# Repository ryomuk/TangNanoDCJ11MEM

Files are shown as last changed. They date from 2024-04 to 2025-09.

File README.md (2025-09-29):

# TangNanoDCJ11MEM
Memory system and UART implemented on Tang Nano 20K for DEC DCJ11 PDP-11 Processor

This document is written mostly in Japanese. If necessary, please use a translation service such as DeepL (I recommend this) or Google.

- 本プロジェクトはTang Console 138Kを用いた続編[TangConsoleDCJ11MEM](https://github.com/ryomuk/TangConsoleDCJ11MEM)があります．
- このREADMEおよび[hdl.old](./hdl.old)フォルダ配下のREADMEに書かれている不安定である旨の記述は2024年に作成したrev1.1基板のものです．rev.2.2になってかなり安定しましたが，記録として残しておきます．

# 概要
- PDP-11の命令セットを持つCPU「DEC DCJ11」のメモリシステムとUARTをFPGA(TangNano20K)上に実装する試みです．信号のインターフェース部分に[tangNano-5V](https://github.com/ryomuk/tangnano-5V)を使用しています．(rev.3.1基板では不要)
- FPGAに実装するのはメモリやUARTなどの周辺回路部分だけで，CPU自体は本物を使用します．ソフトウェアやFPGAによるシミュレータやエミュレータではなく，本物のCPUを動かします．
- "TangNanoDCJ11"だとTangNano上にDCJ11を実装したみたいな名前になってしまうので，"MEM"を付けて"TangNanoDCJ11MEM"という名前になっています．
- まずベアメタルで動かしたところ安定して動きました．
- 次に，PC-11(Paper-Tape Reader/Punch)エミュレータでPaper-Tape BASICをロードして実行することができました．
- さらに，UNIX first edition (UNIX V1)を動かすために，ディスク(RF11, RK11)や外部演算装置(KE11)のエミュレータを実装したところ，それなりに動くようになりました．

# 最近の話題
- 2025/09/03: 本プロジェクトの続編[TangConsoleDCJ11MEM](https://github.com/ryomuk/TangConsoleDCJ11MEM)を公開
- 2025/09/05: rev2.2基板公開
- 2025/09/22: レベル変換ICを搭載した基板rev3.1を公開
- 2025/09/29: RT-11 v4用のHDLを公開
- 最新版は下記の通り
  - レベル変換外付け版([rev2.2](pcb/rev2.2))．(別途[TangNano5V](https://github.com/ryomuk/tangnano-5V)が必要です．)
  - レベル変換搭載版([rev3.1](pcb/rev3.1))
  - 上記のどちらもHDLコードは共通です．
    - [UNIX用のHDLコード](./hdl/unix)(unix-v1, unix-v6 共通)
    - [tapebasic用のHDLコード](./hdl/tapebasic)
    - [RT11v4用のHDLコード](./hdl/rt11v4)

# 主なファイル一覧
```
.
├── diskimage : SDメモリ用データ
│   ├── Caldera-license.pdf : UNIXのライセンス条項
│   ├── sd-unix-v1.dsk      : unix v1用disk image
│   └── sd-unix-v6.dsk      : unix v6用disk image
├── hdl              : rev2.2, rev3.1基板用HDLコード
│   ├── rt11v4
│   ├── tapebasic
│   └── unix
├── hdl.old          : rev1.1基板用HDLコード
│   ├── baremetal
│   ├── tapebasic
│   ├── unix-v1
│   └── unix-v6
├── pcb
│   ├── rev1.1      : rev1.1基板
│   ├── rev2.2      : rev2.2基板
│   └── rev3.1      : rev3.1基板
└── README.md        : このファイル
```
- diskimageフォルダ内にあるSDメモリ用のイメージファイルはUNIXのオリジナルソースからの派生物なので，ライセンス条件は Caldera-license.pdf (昔のBSD?)に従います．
- その他の部分についてはMITライセンスです．

## Gowin FPGA Designerの設定について
- implフォルダをgitから除外したら設定ファイルも除外されてしまったのでコンパイル時にエラーが出るかもしれません．Configuration->Dual-Purpose Pin で"Use SSPI as regular IO"をチェックし下さい．
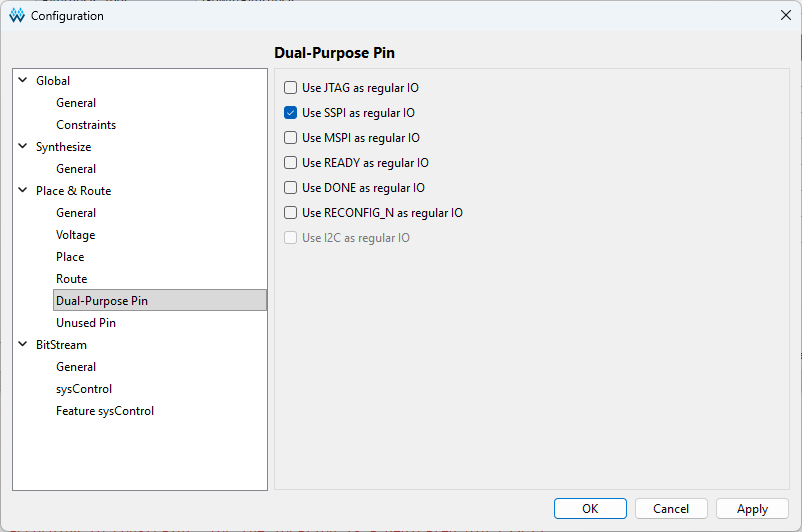
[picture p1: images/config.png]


# 基板のバージョンについて
- [TangConsole138Kを用いたプロジェクト](https://github.com/ryomuk/TangConsoleDCJ11MEM)を開始した際に，CLK2に同期させるとかなり安定するという知見が得られたので，アップデートするついでに各種パッチを反映させた基板(rev2.2)を作成しました．
- ついでに，レベル変換を搭載した基板(rev3.1)も作成しました．
- それぞれの基板は下記のような関係にあります．
```
rev1.1
↓ unix v1, v6用パターンカット，ジャンパ, HALTのダイオード追加, CLK2同期化
rev2.2
↓ レベル変換(TangNano5V相当)を基板上に搭載(CPUの入力信号(FPGA→CPU)については省略)
rev3.1
```
- rev1.1基板に「unix-v1, v6用のパターンカット，ジャンパ線」，「CLK2とGPIO_RXを33Ωで接続」，「HALTのダイオード」を追加することでrev2.2基板と同じ回路になり，rev2.2基板用のHDLコードで動作します．
- rev3.1基板はrev2.2基板にレベル変換を搭載しただけなので同じHDLコードが動きます．
- rev1.1基板用のHDLコードはrev2.2, rev3.1基板では動きません．

# ハードウェア
## FPGAに実装した機能
- Initialization Sequence時のPower-Up Configuration Register設定
- メモリ 32K×16bit
- UART．TangNanoのUSB経由およびGPIO経由の2系統．シリアルの設定は基本的には115200bps,8N1Nにしています．(UNIX V6だと7N1Nにしないと文字化けする現象あり．)
- BS0, BS1は見ていません．TangNano20Kではピンが足りなかったのと，DAL[15:0]とAIO[3:0]を見ればとりあえず十分だったので．
- DAL[21:16]も見ていません．
- PC-11(Paper-Tape Reader/Punch)エミュレータを実装しました．(Paper tape BASICを実行する用で，UNIXでは動きません．)
- ディスクドライブ(RF11, RK11)，外部演算装置(KE11-A)，クロック(KW11-L)等，UNIX V1の動作に必要な装置のエミュレータを実装しました．

## rev3.1基板 (PCB rev3.1)
- レベル変換ICを基板上に実装しました．これによりTang Nano 20KをTangNano5Vを使わずに直接搭載できます．
- ピンアサインはrev2.2基板と同じなので，FPGA用のコードはrev2.2用のものを使用します．
- WS2812のアレイを接続するための端子を用意しました．
- レベル変換ICのOE_nをdisableにしてCPUとTangNanoを切り離すためのジャンパ端子を用意しました．(初めて搭載するときなど，FPGAに別の回路が書かれているようなとき用．)
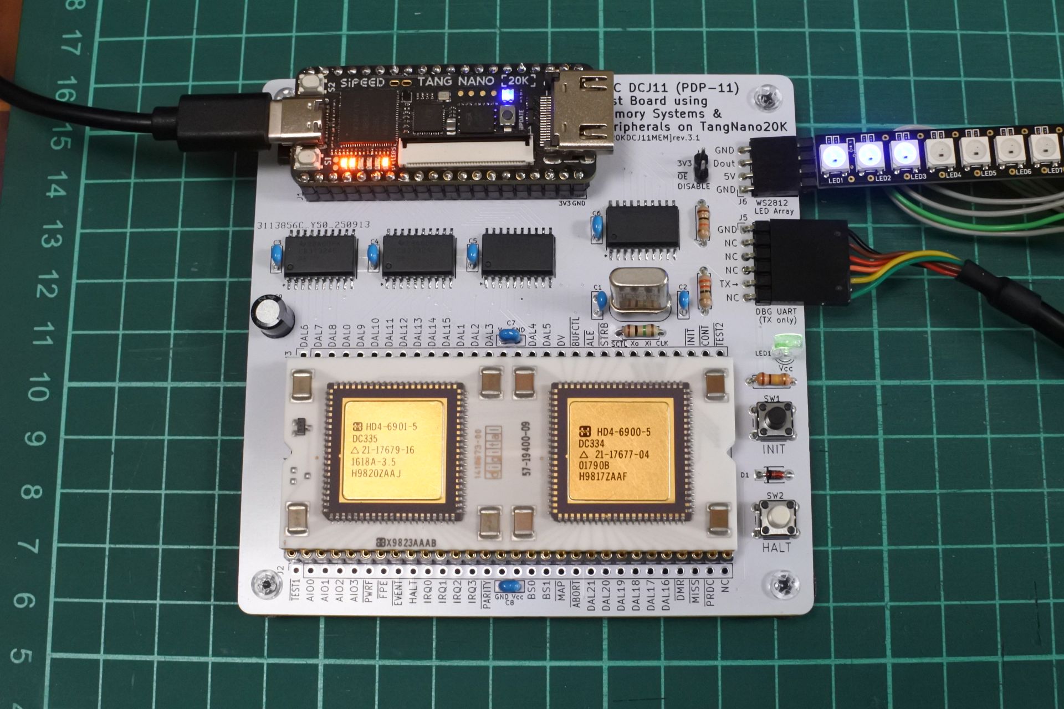
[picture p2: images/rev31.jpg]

#### BOM (PCB rev3.1)
|Reference |Qty| Value |Size |Memo |
|---|---|---|-----|-----|
|C1,C2|2|68pF|||
|C3,C4, C5, C6|4|0.1uF|||
|C7,C8|2|0.33uF|||
|C9 |1|47uF|||
|D1 |1|1N4148|||
|J1 |1|IC socket |40pin DIP 800mil|TangNano20K用．幅800milなので1x20のpin socketを2列実装．|
|J2,J3|2  |pin header or socket|1x30|任意．テストや観測，実験用．|
|J4 |1  |pin header |1x02|任意．OE_nをdisableにする用|
|J5 |1  |pin socket |1x04 L字|WS2812アレイ用|
|J6 |1  |pin header |1x06 L字|UART用|
|LED1 |1||||
|R1 |1|1M|||
|R2 |1|33|||
|R3,R4,R5,R6,R7,R8,R9,R10,R11,R12,R13,R14,R15|13|10k|
|R16|1|100k  || 値はLEDに合わせて任意．|
|SW1,SW2  |2  |tactile SW |6mmxH4.3mm|例: https://akizukidenshi.com/catalog/g/g103647/ |
|U1 |1  |DCJ11 |60pin DIP 1300mil| 1x30 の丸ピンソケット2列|
|U2,U3,U4,U5  |4  |SN74CB3T3245DWR(又は DW) | SOIC-20| パッケージサイズに注意|

|Y1                 |1  |18MHz           |HC49|例: https://mou.sr/3WcWExh , 周波数を変えられるようにソケットの使用をお勧めします．|

- SN74CB3T3245はパッケージサイズに注意．SOIC-20はDWかDWRです．PWやPWRではありません．
- R2は"33k"ではなく"33"です．ダンピング抵抗なので．
- R12，最近のLEDは明るいので100kぐらいでちょうど良かったりします．使うLEDに応じて適切な値を選んで下さい．

## rev2.2基板 (PCB rev2.2)
- rev1.1基板でunixを動かすために必要だったパターンカットとジャンパ配線を反映させました．
- CLK2をGPIO_RXだったピンに入力して，回路をCPUのクロックと同期させました．
- 上記に伴い，基板のUART端子はデバッグログ用のTXだけになりました．
- 電源供給をTangNanoからだけにしてDCジャックを廃止しました．
- HALTスイッチのところの抵抗をダイオードに変更しました．
- unix(v1, v6)を動作させるためのプロジェクトは[hdl/unix](hdl/unix/)を使用して下さい．
- SDメモリ用のイメージファイルは[./diskimage](./diskimage)にあるものがそのまま使えます．
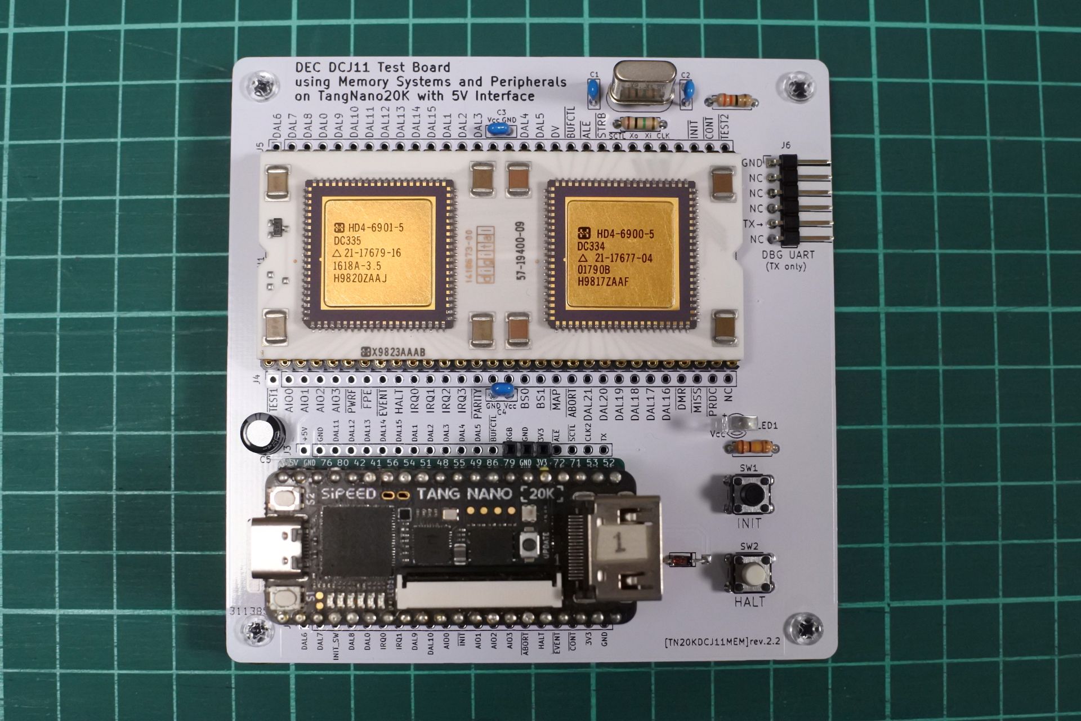
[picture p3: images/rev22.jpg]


#### BOM (PCB rev2.2)
|Reference |Qty| Value |Size |Memo |
|---|---|---|-----|-----|
|C1, C2|2|68pF|||
|C3, C4|2|0.33uF|||
|C5 |1|47uF|||
|D1 |1|1N4148|||
|J1 |1|IC socket |40pin DIP 600mil|TangNano5V用．1x20のpin socket 2列でも可．|
|J2,J3 |2|pin header or socket|1x20|任意．テストや観測，実験用．|
|J4,J5 |2  |pin header or socket|1x30|任意．テストや観測，実験用．|
|J6 |1  |pin header |1x06 L字|UART用|
|LED1 |1||||
|R1 |1|1M|||
|R2 |1|33|||
|R3,R4,R5,R6,R7,R8,R9,R10,R11,R12,R13,R14|12|10k|
|R15|1|100k  || 値はLEDに合わせて任意．|
|SW1,SW2  |2  |tactile SW |6mmxH4.3mm|例: https://akizukidenshi.com/catalog/g/g103647/ |
|U1 |1  |DCJ11 |60pin DIP 1300mil| 1x30 の丸ピンソケット2列|
|Y1 |1  |18MHz |HC49|例: https://mou.sr/3WcWExh , 周波数を変えられるようにソケットの使用をお勧めします．|

## rev1.1基板 (PCB rev1.1)
- rev1.0はいくつか修正箇所があったので修正しました．
- CPUが白いので基板も白くしてみました．
- CPUおよびTangNanoの電源をどこから供給するかを2箇所のジャンパで切り替えられるようにしました．詳細は回路図と基板上のシルクを見て下さい．
- プルダウン抵抗(R2〜R6)を100kから10kに変更しました．(rev1.1a)
- UNIXを動かすにはJP1のパターンのカット，数本のジャンパ配線が必要です．詳細は[UNIX V1](hdl.old/unix-v1/)参照．
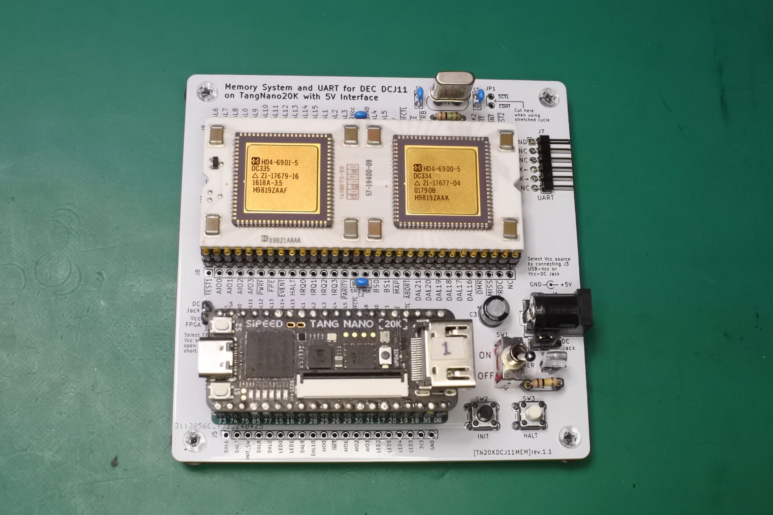
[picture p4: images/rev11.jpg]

#### BOM (PCB rev1.1)
|Reference |Qty| Value |Size |Memo |
|---|---|---|-----|-----|
|C1,C2 |2	|0.33uF	 ||DECのプロセッサボードで0.33uFを使っていたので．0.1uFでもいいかもしれない．|
|C3 |1  |47uF |||
|C4,C5 |2  |68pF |||
|D1 |1  |LED || |
|J1 |1  |DC Jack ||例: https://akizukidenshi.com/catalog/g/g106568/ |
|J2 |1  |pin header |1x02|DC Jackからの5VをTangNanoに供給するとき用．(そのときはTangNanoのUSBは外すこと)．|
|J3 |1  |pin header |1x03|CPUへの5VをDC JackからにするかUSB(TangNano)からにするかの選択用．|
|J4 |1  |IC socket |40pin DIP 600mil|TangNano5V用．1x20のpin socket 2列でも可．|
|J5,J6 |2  |pin header or socket|1x20|任意．テストや観測，実験用．|
|J7 |1  |pin header |1x06 L字|UART用|
|J8,J9 |2  |pin header or socket|1x30|任意．テストや観測，実験用．|
|JP1 | | ||任意．sctl_nとcont_nを切断したときにpin headerを立てる用．実装する場合は先にパターンをカットして下さい．(unix-v1では切断して使います)|
|R1 |1  |100k || 値はLEDに合わせて任意．|
|R2～R6 |5 |10k || プルダウン用．入力電流がmax10μAなので大きめでいいかと思ったら意外にノイズが大きいので100kから10kに変更しました．|
|R7～R16 |10 |100k || プルアップ用．10k〜100kぐらいで任意．|
|R17 |1  |1M |||
|SW1 |1  |toggle SW ||例: https://akizukidenshi.com/catalog/g/g100300/ |
|SW2,SW3 |2  |tactile SW |6mmxH4.3mm|例: https://akizukidenshi.com/catalog/g/g103647/ |
|U1 |1  |DCJ11 |60pin DIP 1300mil| 1x30 の丸ピンソケット2列|
|Y1 |1  |18MHz |HC49|例: https://mou.sr/3WcWExh , 低速(2MHzで確認済み,もっと遅くても動きそう)でも動きます．周波数を変えられるようにソケットの使用をお勧めします．|

# [応用例(hdl.old/)](hdl.old/)
## [ベアメタル(hdl.old/baremetal)](hdl.old/baremetal/)
- クロス環境で作成したプログラムを実行します．
- HDLは小規模なので，いろいろ試すベースラインに最適です．

## [tape basic(hdl.old/tapebasic)](hdl.old/tapebasic/)
- 二次記憶をエミュレートするために手始めに作った習作です．
- PC11(tape reader/pucnch)エミュレータで，tape BASICを読み込んで起動します．
- SDメモリを使う練習用に作ったものなのでとりあえず動きます程度のものです．
- PDP11GUIに，console ODT経由でpaper tape softwareをロードする機能があるようなので，いろいろなpaper tape softwareを試すという目的であればベアメタルでPDP11GUIを使うことをお勧めします．

## [UNIX V1(hdl.old/unix-v1)](hdl.old/unix-v1/)
- SDメモリを使ったdiskエミュレータを作成し，UNIX V1を動かしてみました．
- 最初はかなり不安定でしたが，だいぶ安定して動くようになってきました．

## [UNIX V6(hdl.old/unix-v6)](hdl.old/unix-v6/)(実験用)
- unix-v1用をベースにUNIX V6に必要な機能を逐次追加中です．修正のたびにV1の動作確認をするのは面倒なのでV1用と分けることにしました．

# 動画
- [PDP-11 Paper-Tape BASIC running on DCJ-11 Processor](https://www.youtube.com/watch?v=F_eFMz5ysK8)

- [UNIX V1 on DEC DCJ-11 with TangNano 20K (under development)](https://www.youtube.com/watch?v=DT7xJWeF46Y)

- [UNIX V1 on DEC DCJ-11 with TangNano 20K](https://www.youtube.com/watch?v=G9AFgAaTexo)

# 旧版
## ブレッドボード版
- console ODT(Octal Debug Technique)の動作確認をするところから始めて，[豊四季タイニーBASIC](https://github.com/vintagechips/ttbasic_arduino)を軽微な修正で動かせるところまで確認しました．
- クロックは18MHzで動きました．遅い方は2MHzでも動きました．
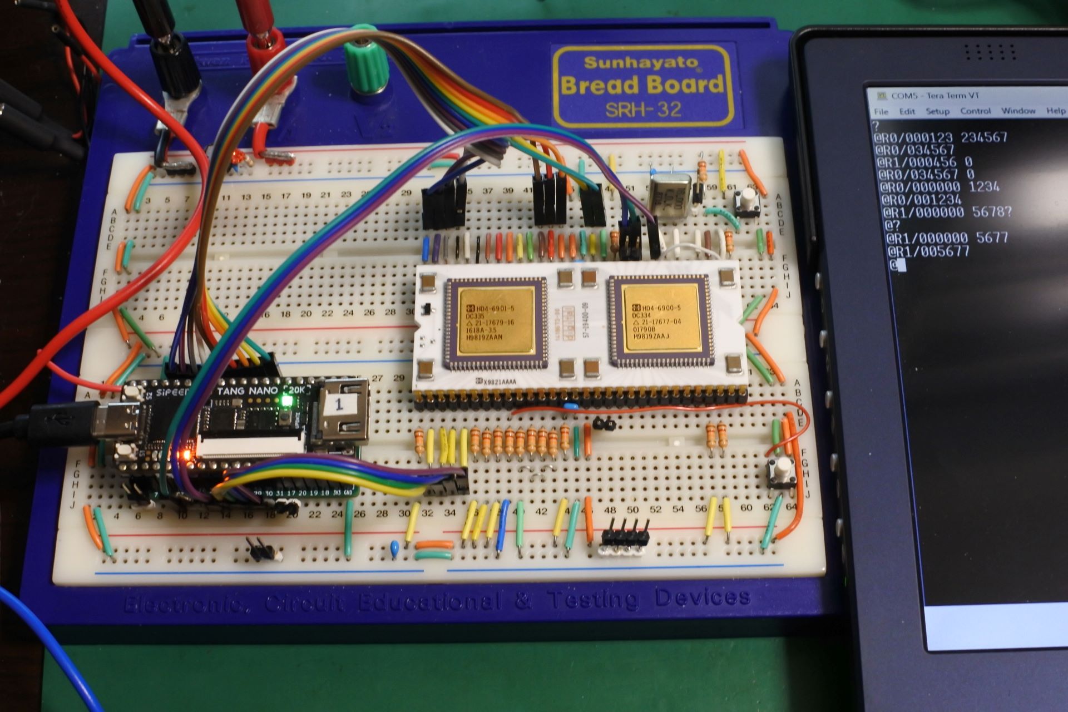
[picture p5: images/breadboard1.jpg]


## PCB版 rev1.0
最初に作った基板です．とりあえず動きました．
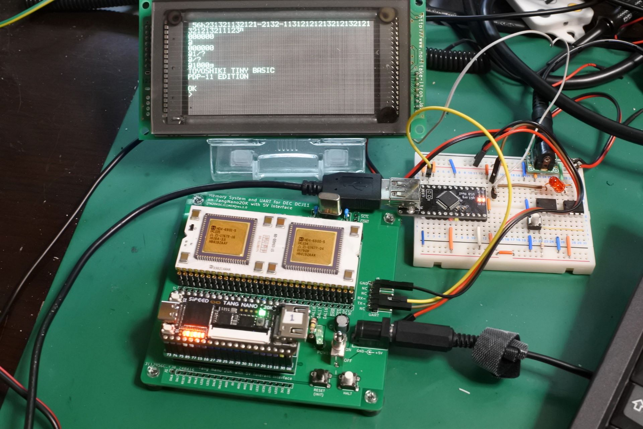
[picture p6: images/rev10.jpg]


# 関連情報
## データシート等
### bitsavers
- [DCJ11 Microprocessor User's Guide](http://www.bitsavers.org/pdf/dec/pdp11/1173/EK-DCJ11-UG-PRE_J11ug_Oct83.pdf), DEC, EK-DCJ11-UG-PRE(Preliminary)
- [Index of /pdf/dec/pdp11/j11](http://bitsavers.trailing-edge.com/pdf/dec/pdp11/j11/)
- [Index of /pdf/dec/pdp11/1173](http://bitsavers.trailing-edge.com/pdf/dec/pdp11/1173/)

## 先行事例，先駆者たち
- [PDP-11/HACK](http://madrona.ca/e/pdp11hack/index.html), Brent Hilpert
- [My PDP-11 Projects](https://www.5volts.ch/pages/pdp11hack/), Peter Schranz
- [PDP11 on a breadboard A.K.A. J11 Hack](https://www.chronworks.com/J11/), Len Bayles
- [S100 Bus PDP-11 CPU Board](http://www.s100computers.com/My%20System%20Pages/PDP11%20Board/PDP11%20Board.htm), John Monahan

## 開発環境関連
- [PDP-11(エミュ）上でCで"Hello, World!"](https://qiita.com/hifistar/items/8eff4a73087f3a41e19f), hifistar
- [PDP-11のgccクロスコンパイル環境の構築メモ](https://qiita.com/hifistar/items/187fd7ad780c6aa26141), hifistar
- [SimH (History Simulator)](http://simh.trailing-edge.com/)
- [j-hoppe/PDP11GUI](https://github.com/j-hoppe/PDP11GUI)

## Paper Tape Software関連
- [Paper Tape Archive](https://www.vaxhaven.com/Paper_Tape_Archive)
- [DEC PDP-11 Paper Tape Images](https://www.pcjs.org/software/dec/pdp11/tapes/)
- [PDP-11 Paper Tape BASIC](https://avitech.com.au/?page_id=709)
- [Learning PDP-11](https://www.learningpdp11.com/) Paper Tape BASICとboot loaderについてとても詳しく解説されています

## UNIX関連
- [The Unix Heritage Society](https://www.tuhs.org/)
- [V1](https://www.tuhs.org/cgi-bin/utree.pl?file=V1)
- [UNIX First Edition](https://gunkies.org/wiki/UNIX_First_Edition)
- [jserv/unix-v1](https://github.com/jserv/unix-v1)

## 関連記事
- [きょうのかんぱぱ](https://kanpapa.com/today/)
TangNanoDCJ11MEMを使って私がやっていないようなことまでやっていたり，ここのREADMEより詳しく解説されてたりします．
  - [TangNanoDCJ11MEMでPDP-11のCPUを動かしてみました 製作編](https://kanpapa.com/today/2024/07/pdp-11-dcj11-cpu-1.html), 
  - [TangNanoDCJ11MEMでPDP-11のCPUを動かしてみました bare metal編](https://kanpapa.com/today/2024/07/tangnanodcj11mem-pdp-11-cpu-2-bare-metal.html)
  - [TangNanoDCJ11MEMとPDP11GUIでPDP-11 BASICを動かしてみました](https://kanpapa.com/today/2024/08/tangnanodcj11mem-pdp-11-cpu-3-pdp11basic.html)
  - [PDP-11 DCJ11 CPUでUNIX v6を動かしてみました](https://kanpapa.com/today/2024/08/tangnanodcj11mem-pdp-11-cpu-4-unix-v6.html)
  - [PDP-11 DCJ11 CPUでMINI-UNIXを動かしてみました](https://kanpapa.com/today/2024/08/tangnanodcj11mem-pdp-11-dcj11-cpu-mini-unix.html)

# 更新履歴
- 2024/04/25: 初版公開
- 2024/04/25: README修正(BOM追加)
- 2024/05/05: 基板rev1.1の写真追加．project更新．
- 2024/05/05: README.md修正(開発環境関連の情報を追加)
- 2024/05/05: samplesにasciiart を追加
- 2024/05/22: PC-11(紙テープリーダ/パンチャ)エミュレータを実装
- 2024/06/19: SDHCの初期化部分にバグがあったので修正
- 2024/06/21: tapebasicのtop.vにバグがあったので修正
- 2024/06/21: baremetalとtapebasicを別フォルダに分離．READMEも分離．
- 2024/06/24: unix-v1用の開発中HDLを公開(かなり不安定です)
- 2024/06/28: tapebasicのtapeimage.datの作成方法を修正
- 2024/06/28: tapebasicのtapeimage.datの作成方法を修正
- 2024/07/07: baremetal版修正(UART安定化, 20240707公開)
- 2024/07/12: unix-v1版修正(20240712.alpha公開)
- 2024/07/13: unix-v1版修正(20240713.alpha公開)．IRQのジャンパ変更．
- 2024/07/14: unix-v1版修正(20240714.alpha公開)．デバッグ用レジスタ変更．
- 2024/07/15: プルダウン抵抗(R2〜R6)を100kから10kに変更．100kで問題が起きていなければ変える必要は無いです．
- 2024/07/16: unix-v1版大規模修正(20240716.beta公開)．JP1(SCTL_nとCONT_nを接続してるパターンをカットして下さい．)
- 2024/07/19: unix-v1 20240719.beta 公開．これまでのバージョンと比較するとだいぶ安定しました．
- 2024/07/27: unix-v1 20240727.beta 公開．
- 2024/07/28: unix-v1 20240728.beta 公開．(UNIX V6実験用機能追加)
- 2024/07/29: V6実験用とV1用を分離しました．
  - unix-v1 20240729.beta 公開．
  - unix-v6 20240729.v6.beta 公開．
- 2025/09/04: rev2.0基板公開．
- 2025/09/05: rev2.2基板公開．
- 2025/09/06: README修正(HALTのジャンパ関連(main, unix-v1, unix-v6), rev3基板予告)
- 2025/09/15: 20250915.pcbrev2 公開．(LEDアレイ用の記述を追加)
- 2025/09/17: 20250917.pcbrev2 公開．(SDメモリ無しで動かすときの問題を修正)
- 2025/09/22: フォルダ構成変更．
  - rev3.1基板公開．
  - 20250922公開．
- 2025/09/29: RT11 v4用HDL公開．

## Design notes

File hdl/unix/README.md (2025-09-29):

# TangNanoDCJ11MEM (unix for rev2.2 and rev3.1 PCB)

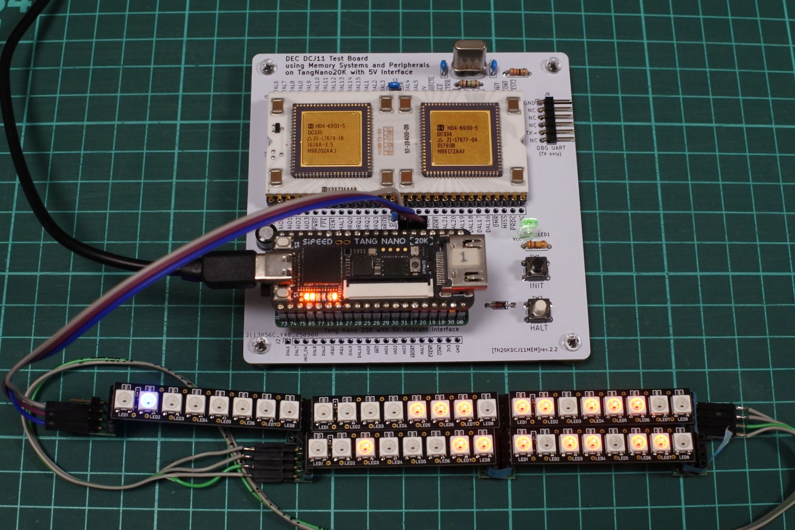
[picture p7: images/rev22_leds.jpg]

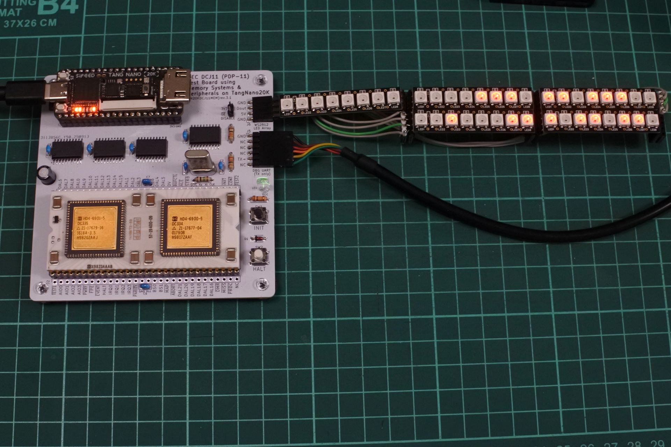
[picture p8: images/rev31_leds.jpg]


- [unix-v1](../../hdl.old/unix-v1/)，[unix-v6](../../hdl.old/unix-v6/)で必要だったパターンカットとジャンパ線を反映させた基板であるrev2.2基板，およびそれにレベル変換ICを追加したrev3.1基板用のHDLコードです．

- FPGAのクロックをCPUからのCLK2に同期させることによってかなり安定して動くようになりました．
- unix v1, v6が起動します．(SDメモリはそれぞれ別に用意する必要があります．)
  - 使い方はrev1.1基板の[unix-v1](../../hdl.old/unix-v1/)，[unix-v6](../../hdl.old/unix-v6/)と同じです．
    - 173000g でv1用ブートローダ起動
    - 174000g でv6用ブートローダ起動．'@'でunixと入力する．
- rev1.1基板でも，CPUのCLK2を33Ω程度のダンピング抵抗をはさんでGPIO_RXに接続すればrev2.2用のHDLコードで動作します．
```
DCJ11               rev1.1基板
CLK2 ---33Ω抵抗--- GPIO_RX
```
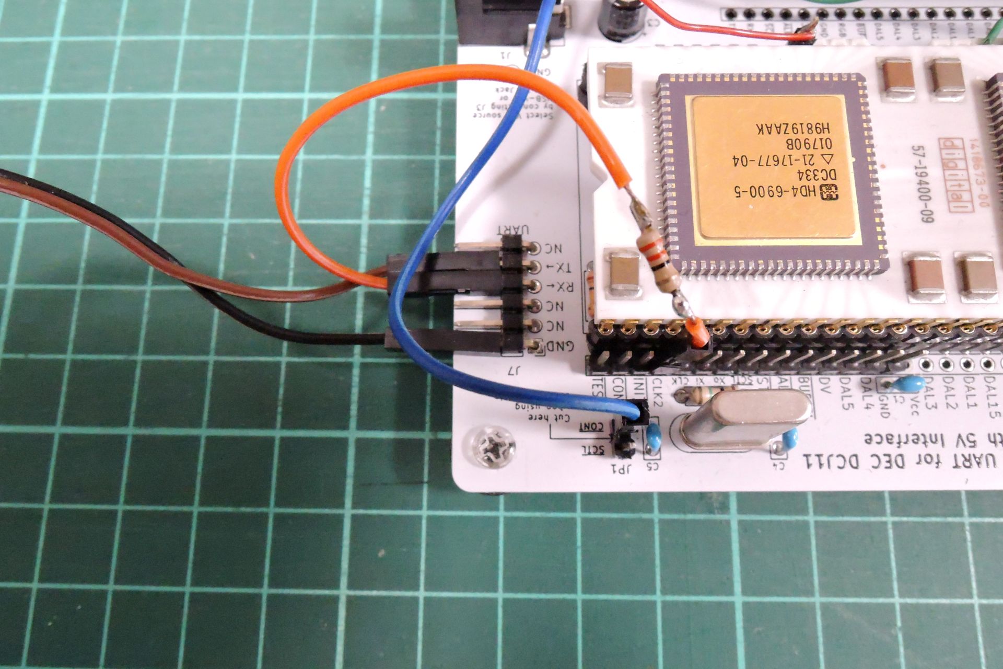
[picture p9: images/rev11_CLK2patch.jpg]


- RGB, GND, 3V3をWS2812に接続するとアドレスやデータを表示します．Aliで売られている安いLEDテープでも動作しました．

# 関連情報
- かんぱぱさんからMINI-UNIXを動作させたという報告をいただきました
  - [きょうのかんぱぱ「PDP-11 DCJ11 CPUでMINI-UNIXを動かしてみました」](https://kanpapa.com/2024/08/tangnanodcj11mem-pdp-11-dcj11-cpu-mini-unix.html)

# 更新履歴
- 2025/09/04: 20250904.pcbrev2
- 2025/09/15: 20250915.pcbrev2 (ws2812モジュール修正)
- 2025/09/17: 20250917.pcbrev2 (SDメモリ無しで起動するとスタックしてリセットも効かなくなる問題を修正)
- 2025/09/22: 20250922 デバッグ用LED表示をsw2で切り変える機能を追加

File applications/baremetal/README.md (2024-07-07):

# TangNanoDCJ11MEM (baremetal)
- クロス環境で作成したプログラムを実行します．
- HDLは小規模なので，いろいろ試すベースラインに最適です．

# PDP-11用プログラム開発環境
## クロス環境の構築
下記リンクにある情報が大変参考になりました．
- [PDP-11のgccクロスコンパイル環境の構築メモ](https://qiita.com/hifistar/items/187fd7ad780c6aa26141), by hifistar
- [PDP-11(エミュ）上でCで"Hello, World!"](https://qiita.com/hifistar/items/8eff4a73087f3a41e19f), by hifistar

これに従ってVMwareのubuntu上にクロス環境を構築し、実機で動くプログラムのバイナリを作成できました。
バージョンが古かったり，いくつか誤りもあったので下記のように修正しています。

- pkginst.shの先頭を/bin/shから/bin/bashに変更．(pushd でエラーになったので)
- ツール類のバージョンを最新か新しめの値に修正．
  - binutils-2.42
  - gmp-6.3.0
  - mpfr-4.2.1
  - mpc-1.3.1
  - gcc-11.4.0
- start.Sの"mov $0x1000, sp"はおそらく"$01000"の間違いなので修正．

## サンプルプログラム
### マンデルブロ集合表示プログラム [samples/asciiart](samples/asciiart)
- クロス環境でコンパイルできます．
- a.outからrom.vへの変換はtools/out2rom.pl を使用．かなり適当に変換してます．
- makeしてできるrom.asciiart.v をrom.vにリネームしてTangNano用プロジェクトに持って行ってビルドします。
- console ODTから，1000g で実行．~~UART関連がまだ不安定なので文字化けすることがあります．~~ (sys_clkに同期化したら安定しました．)
- 起動時にconsole ODTを起動するか，ユーザプログラムを起動するかは，top.vのPUP_CONFで設定可能です．

## シミュレータ
実機で動かす前の動作確認に使えます．後から気がついたのですが，ubuntuだと古いバージョンならapt install simhでインストールできるようでした．
- [SimH (History Simulator)](http://simh.trailing-edge.com/)
- simhv312-4.zipをとってきてmake
- PDP11/pdp11_defs.hの「uint32 uc15_memsize;」 がリンク時にmultiple definitionのエラーになるのでextern uint32に変更したらコンパイルできました．

## GUI開発環境
シリアルポート経由でconsole ODTをGUI操作できるようになるツールです．こんなものがあるとは驚きました．
- [j-hoppe/PDP11GUI](https://github.com/j-hoppe/PDP11GUI)

## 更新履歴
- 2024/06/24: 初版公開(20240624)
- 2024/07/07: UART安定化(20240707)

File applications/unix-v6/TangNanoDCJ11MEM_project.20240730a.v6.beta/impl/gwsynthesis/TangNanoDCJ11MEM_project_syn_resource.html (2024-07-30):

# Hierarchy Module Resource

MODULE NAME | REG NUMBER | ALU NUMBER | LUT NUMBER | DSP NUMBER | BSRAM NUMBER | SSRAM NUMBER | ROM16 NUMBER
top (C:/wks/ework/FPGA/TangNano/20k/TangNanoDCJ11MEM/TangNanoDCJ11MEM_project/src/top.v) | 2269 | 248 | 3872 | 1 | 32 | - | -
|--integer_division (C:/wks/ework/FPGA/TangNano/20k/TangNanoDCJ11MEM/TangNanoDCJ11MEM_project/src/top.v) | 2314 | 1093 | 298 | - | - | - | -
|--uart_rx_inst (C:/wks/ework/FPGA/TangNano/20k/TangNanoDCJ11MEM/TangNanoDCJ11MEM_project/src/top.v) | 44 | 19 | 33 | - | - | - | -
|--uart_tx_inst (C:/wks/ework/FPGA/TangNano/20k/TangNanoDCJ11MEM/TangNanoDCJ11MEM_project/src/top.v) | 62 | 21 | 101 | - | 1 | - | -
|--sdhd_inst (C:/wks/ework/FPGA/TangNano/20k/TangNanoDCJ11MEM/TangNanoDCJ11MEM_project/src/top.v) | 396 | 98 | 588 | - | 1 | 2 | -
|--onboard_rgb_led (C:/wks/ework/FPGA/TangNano/20k/TangNanoDCJ11MEM/TangNanoDCJ11MEM_project/src/top.v) | 45 | - | 80 | - | - | - | -
|--uart_tx_inst_dbg (C:/wks/ework/FPGA/TangNano/20k/TangNanoDCJ11MEM/TangNanoDCJ11MEM_project/src/top.v) | 62 | 21 | 101 | - | 1 | - | -

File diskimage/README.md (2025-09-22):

このフォルダにあるイメージファイルは Caldera-license.pdf に記載されている
ライセンス条件の下に配布しています．
These disk images are distributed under the license notice Caldera-license.pdf

Caldera-license.pdf : License Notice by Caldera International, Inc.
sd-unix-v1.dsk : disk image of unix v1
sd-unix-v6.dsk : disk image of unix v6

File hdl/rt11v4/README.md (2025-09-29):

# TangNanoDCJ11MEM (rt11v4 for rev2.2 and rev3.1 PCB)

## 概要
- [unix用のHDL](../unix/)とほとんど同じものです．rev2.2基板，rev3.1基板，パッチを当てたrev1.1基板で動作します．
- bootの途中で何かのフラグのクリアを待つループに入って止まってしまっていたのを，TTY outの割り込みを無理矢理入れることで起動するようになりました．汚い対処ですが，一応動くのでとりあえず公開します．

## 使い方
- [wfjm's Home Available OS Kits](https://wfjm.github.io/home/w11/inst/systems.html) にあるRT11 V4.0 rksetの中のrtv4_rk.dskを下記の手順でsdメモリ用のイメージsd.dskにしてSDメモリに書き込みます．
  - /dev/xxx は生のsdメモリの場所です．(先頭のブロックから書くので数字が付いてないやつ．'fdisk -l'等で調べて下さい．) 間違えるとパソコンの他のファイルシステムを破壊するので厳重に注意して行って下さい．

```
dd if=/dev/zero of=sd.dsk bs=512 count=1024
dd if=rtv4_rk.dsk of=sd.dsk bs=512 seek=1024 conv=notrunc

dd if=sd.dsk of=/dev/xxx ← SDメモリの場所
```
- 起動の様子
```
@774000g
RT-11SJ  V04.00C

.D 56=5015

.TYPE V4USER.TXT
Welcome to RT-11 Version 4. RT-11 V04 provides new hardware support
and some major enhancements over Version 3B.

Please use the HELP command;  it describes the new options in many
of the utilities.

If you are using a terminal that requires fill characters,
modify location 56 with a Deposit command before proceeding with
system installation. LA36 DECwriter II and VT52 DECscope terminals
do NOT require such modification.

.D 56=0

.DIR

SWAP  .SYS    25  01-Feb-82      RT11BL.SYS    65  01-Feb-82
RT11SJ.SYS    67  01-Feb-82      RT11FB.SYS    80  01-Feb-82
TT    .SYS     2  01-Feb-82      DT    .SYS     3  01-Feb-82
DP    .SYS     3  01-Feb-82      DX    .SYS     3  01-Feb-82
DY    .SYS     4  01-Feb-82      RF    .SYS     3  01-Feb-82
RK    .SYS     3  01-Feb-82      DL    .SYS     4  01-Feb-82
DM    .SYS     5  01-Feb-82      DS    .SYS     3  01-Feb-82
DD    .SYS     5  01-Feb-82      MT    .SYS     9  01-Feb-82
MM    .SYS     9  01-Feb-82      MS    .SYS    10  01-Feb-82
LP    .SYS     2  01-Feb-82      LS    .SYS     2  01-Feb-82
CR    .SYS     3  01-Feb-82      NL    .SYS     2  01-Feb-82
PC    .SYS     2  01-Feb-82      PD    .SYS     3  01-Feb-82
CT    .SYS     6  01-Feb-82      BA    .SYS     7  01-Feb-82
PIP   .SAV    23  01-Feb-82      DUP   .SAV    41  01-Feb-82
DIR   .SAV    17  01-Feb-82      FORMAT.SAV    19  01-Feb-82
SLP   .SAV     9  01-Feb-82      SIPP  .SAV    20  01-Feb-82
STARTS.COM     1  01-Feb-82      STARTF.COM     1  01-Feb-82
V4USER.TXT     1  01-Feb-82      CREF  .SAV     6  01-Feb-82
DUMP  .SAV     8  01-Feb-82      MBOT16.BOT     1  01-Feb-82
RESORC.SAV    15  01-Feb-82      SYSMAC.SML    42  01-Feb-82
EDIT  .SAV    19  01-Feb-82      KED   .SAV    60  01-Feb-82
K52   .SAV    55  01-Feb-82      TECO  .SAV    50  01-Feb-82
MACRO .SAV    51  01-Feb-82      MAC8K .SAV    56  01-Feb-82
LINK  .SAV    41  01-Feb-82      LIBR  .SAV    22  01-Feb-82
FILEX .SAV    18  01-Feb-82      SRCCOM.SAV    13  01-Feb-82
BINCOM.SAV    10  01-Feb-82      MTHD  .SYS     4  01-Feb-82
MMHD  .SYS     4  01-Feb-82      MSHD  .SYS     5  01-Feb-82
PATCH .SAV    10  01-Feb-82      PAT   .SAV     8  01-Feb-82
HELP  .SAV   107  01-Feb-82      HELP  .EXE     7  01-Feb-82
HELP  .MLB    98  01-Feb-82      ERROUT.SAV    17  01-Feb-82
SYSGEN.SAV    39  01-Feb-82      SYSGEN.CND   134  01-Feb-82
SYSTBL.CND    23  01-Feb-82      BATCH .SAV    26  01-Feb-82
QUEMAN.SAV    13  01-Feb-82      QUEUE .REL    14  01-Feb-82
SYSLIB.OBJ    47  01-Feb-82      MDUP  .SAV    18  01-Feb-82
MDUP  .MM     48  01-Feb-82      MDUP  .MT     48  01-Feb-82
MDUP  .MS     48  01-Feb-82      MBOOT .BOT     1  01-Feb-82
MSBOOT.BOT     3  01-Feb-82      DEMOF1.FOR     2  01-Feb-82
DEMOED.TXT     1  01-Feb-82      README.TXT    36  01-Feb-82
VT52  .TEC     5  01-Feb-82      VEG   .TEC     4  01-Feb-82
EDIT  .TEC     1  01-Feb-82      INSERT.TEC     2  01-Feb-82
LOCAL .TEC     3  01-Feb-82      SORT  .TEC     3  01-Feb-82
VTEDIT.TEC    32  01-Feb-82      TECO  .TC     23  01-Feb-82
SEARCH.TEC     3  01-Feb-82      SQU   .TEC    13  01-Feb-82
TYPE  .TEC    12  01-Feb-82      TECO  .INI    15  01-Feb-82
ODT   .OBJ     9  01-Feb-82      VDT   .OBJ     9  01-Feb-82
VTHDLR.OBJ     9  01-Feb-82      PLOT55.OBJ     3  01-Feb-82
TEST55.FOR     5  01-Feb-82      GETSTR.FOR     2  01-Feb-82
PUTSTR.FOR     2  01-Feb-82      SPEED .SAV     4  01-Feb-82
SYCND .BL      3  01-Feb-82      SYSTBL.BL      4  01-Feb-82
SYCND .DIS     5  01-Feb-82      SYCND .HD      5  01-Feb-82
SYSTBL.DIS     4  01-Feb-82      RTBL  .MAP    16  01-Feb-82
RTSJ  .MAP    16  01-Feb-82      RTFB  .MAP    23  01-Feb-82
DISMT1.COM     9  01-Feb-82      DISMT2.COM     8  01-Feb-82
 106 Files, 1942 Blocks
 2820 Free blocks

.
```

# 更新履歴
- 2025/09/29: 20250929(RT-11 v4用HDL)公開

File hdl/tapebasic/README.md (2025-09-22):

# TangNanoDCJ11MEM_project.tape (tapebasic)
- TangNano20KのSDスロットをPC11(tape reader/punch)エミュレータとして起動するHDLです．
- paper tape BASICを読み込んで起動できます．

## PC-11(Paper-Tape Reader/Punch)エミュレータ [sdtape.v](TangNanoDCJ11MEM_project.tape/src/sdtape.v)
- SDメモリに入れた紙テープのイメージを読み込むエミュレータです
- SDメモリはファイルシステム無しの生のままで使うのでddで読み書きします．
- パンチ機能については，BASICのSAVEで書き込むことができたのでとりあえず動いているようですが，SDメモリを不用意に上書きしてしまうのを避けるため，top.vで無効化してあります．
- 2GBのSD(SanDisk), 32GBのSDHC(kioxia), 64GのSDXC(kioxia, SAMSUNG)で動作しました．

使用例:
- [Paper Tape Archive](https://www.vaxhaven.com/Paper_Tape_Archive)から
absolute loader('ABSOLUTE-BINARY-LOADER.ptap')と，Paper Tape BASIC ('DEC-11-AJPB-PB.ptap')を入手し，sdメモリに書き込みます．(頭の000があると読めないようで，先頭の16byteを削除しました．)
- /dev/xxx は生のsdメモリの場所です．(先頭のブロックから書くので数字が付いてないやつ．'fdisk -l'等で調べて下さい．)
- 間違えるとパソコンの他のファイルシステムを破壊するので厳重に注意して行って下さい．

```
cat ABSOLUTE-BINARY-LOADER.ptap DEC-11-AJPB-PB.ptap | dd of=tapeimage.dat bs=1 skip=16
dd if=tapeimage.dat of=/dev/xxx
```
- 上記手順で作成したtapeimage.datを[./data](./data)に置いておきました．
- TangNano20KのSDメモリスロットに入れて電源を入れ，ODT consoleから下記のように
してBASICが起動できます．

```
@157744g   ←bootstrap loader起動してabsolute loaderを読み込む
157500
@157500g   ←absolute loaderを起動してBASICを読み込む
PDP-11 BASIC, VERSION 007A
*O         ←returnを押す(ここでいろいろ初期設定等できるらしい．)
READY
```

# 関連情報
- かんぱぱさんのページにいろいろと詳しい説明がありました．
  - [きょうのかんぱぱ「TangNanoDCJ11MEMとPDP11GUIでPDP-11 BASICを動かしてみました」](https://kanpapa.com/2024/08/tangnanodcj11mem-pdp-11-cpu-3-pdp11basic.html)

# 動画
- [PDP-11 Paper-Tape BASIC running on DCJ-11 Processor](https://www.youtube.com/watch?v=F_eFMz5ysK8)

# 更新履歴
- 2025/9/22: rev2基板用のHDL公開

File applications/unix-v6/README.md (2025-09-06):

# TangNanoDCJ11MEM (unix-v6)
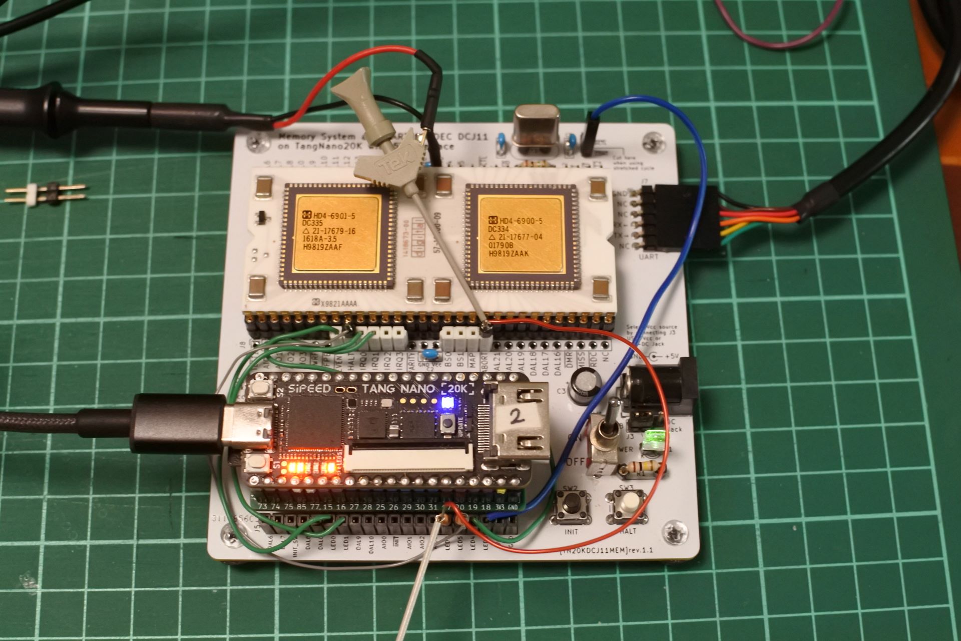
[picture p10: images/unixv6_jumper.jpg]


[unix-v1](../unix-v1/)をベースにしてUNIX V6に必要な機能を逐次追加していく試みです．

## 最近の話題
### 2024/07/30  (0730.v6.beta, 0730a.v6.beta版公開)
- 複数disk drive(rk0, rk1, rk2, rk3,..., rk7)を実装しました．(disk_blockのbit幅を増やすだけだったので最初からやっておけば良かったのですが，UNIX V1には不要だったので…)
- [Installing UNIX v6 (PDP-11) on SIMH](https://gunkies.org/wiki/Installing_UNIX_v6_(PDP-11)_on_SIMH)の手順で作ったrk0,rk1,rk2を/, /usr/source, /usr/docにマウントしてloginできました．(下記「sd用イメージ作成手順」参照)
- tic-tac-tooやbjは動きましたが，chessはtoo largeで動かず。ccもまだ動かないのでまだ問題はありそうです．
- 電源ON時にログが大量に出る問題がありましたので，デバッグログをabortではなくbus errorに修正した0730a.v6.betaも置きました．もしかしたら不具合があるかもしれないので0730.v6.betaも残してあります．

### 2024/07/29 (0729.v6.beta版公開)
- unix-v1用とunix-v6用を別プロジェクトにしました．
- 160000台を全部つぶすのはもったいないのでRAM30KWにしました．
- ABORT_nをトライステートにして，非アサート時は'Z'にしました．
- ABORT_nとLED2は直接ジャンパせずに抵抗を入れて下さい．
- ABORT_nは双方向で，INIT時にDCJ11が'L'にアサートしていてTangNano側が'H'なので，直結だと数十mAの電流が流れてしまうことがわかりました．1KだとTangNano側のアサート時にLレベルまで下がらず，本当は470Ωぐらいにしたいのですが，立ち下がりが間に合わないようなので100Ωで対処しました．
  - → ABORT_nをtri-stateにしてアサート時以外はZにしたので，INIT時の競合は回避できています．TangNanoの出力は'Z'か'L'なので直結でも大丈夫なはずですが，念のため100Ωを入れておくようにします．

- 20240728.beta版以降でUNIX V6実験用の機能を追加しています．(とりあえず作ってみた程度のものです．)
- rkunixが ~~文字化けしながら~~ マルチユーザーで起動しました．
  - → simh用にmkconfしたカーネル(unix)も起動しました．
- 下記の場合にLED2にABORT_n(bus error)を(意図的に)出力します．
  - 177700へのread (power-up sequenceのMicrodiagnostic test 2 用)
  - ~~160000〜167777へのwrite~~
  - ~~160000〜160077~~ 170000〜170077へのread．(mainの最初のcoremap初期化ループのfuibyteをエラーにしてメモリサイズを特定するのに必要．)
- ~~160000~~ 170000〜177777までは書き込みできないROMエリアにしました．(I/Oは除く)
- RK0用ブートストラップローダー
  - RK0のblock 0 (SDメモリのblock 1024)のブートストラッププログラムを0〜776番地(256word(=512byte))にロードして0番地にジャンプします．
  - 174000〜のROMに配置したので，174000g で起動します．(詳細はrom.v参照)
- UNIX V6起動実験について
  - かんぱぱさんの [unix v6の起動にチャレンジ](https://lateral-apartment-215.notion.site/unix-v6-67b9abee6b784c4795d5094cf69c4f96) が大変参考になりました．
  - アドレス空間が18bit必要だと思っていたのですが，28KWのPDP11で動いていたとのことなので試してみることにしました．
  - メモリ容量の判定にbus errorを使っているみたいだったのでABORT_nを実装しました．
  -  DC11は実装していないので，とりあえず最小限の構成のrkunixで試してみたところ， ~~文字化けしながら~~ 起動しました． (PDP11GUI，TeraTermでデータを7bitだと文字化けしなくなりました．)
  - single userはsr(177570)=173030 ですが，マルチユーザーで起動しました．
  - イメージの作成は[Installing_UNIX_v6_(PDP-11)_on_SIMH](https://gunkies.org/wiki/Installing_UNIX_v6_(PDP-11)_on_SIMH)を参考にしています．
  - GPIO UARTの使い方を変更すると起動しなくなることがあります．デバッグ情報出力ありだけで動作確認しています．

## ジャンパ配線等
- IRQ、EVENT、CONT_n、ABORT_n用に下記ジャンパ配線をする。HALTはデバッグ用なので任意。HALTはスイッチと競合するので~~1kΩの抵抗~~ダイオードを付けます。(1kΩ抵抗よりダイオード(1N4148等)の方が良さそうです．DCJ11側がカソードです．)
- ABORT_nは双方向で，INIT時にDCJ11が'L'にアサートしていてTangNano側が'H'なので，直結だと数十mAの電流が流れてしまうことがわかりました．1KだとTangNano側のアサート時にLレベルまで下がらず，本当は470Ωぐらいにしたいのですが，立ち下がりが間に合わないようなので100Ωで対処しました．
  - → ABORT_nをtri-stateにしてアサート時以外はZにしたので，INIT時の競合は回避できています．TangNanoの出力は'Z'か'L'なので直結でも大丈夫なはずですが，念のため100Ωを入れておくようにします．
```
DCJ11       TangNano5V
IRQ0    --- LED0  (ttyi, ttyo用)
IRQ1    --- LED1  (drum(RF), disk(RK)用)
EVENT_n --- LED4  (clock用)
CONT_n  --- LED3  (stretched cycle用)
ABORT_n ---100Ω抵抗--- LED2 (bus error用)

HALT    --- K(1N4148)A --- LED5 (デバッグ用, 無くても可)

```

## sd用イメージ作成手順
- [Installing UNIX v6 (PDP-11) on SIMH](https://gunkies.org/wiki/Installing_UNIX_v6_(PDP-11)_on_SIMH)の手順通りにrk0,rk1,rk2を作ります．
  - ↑リンクが切れているようです．Internet Archiveに保存されてました→ [Feb.27, 2025 Installing UNIX v6 (PDP-11) on SIMH](https://web.archive.org/web/20250227030852/https://gunkies.org/wiki/Installing_UNIX_v6_(PDP-11)_on_SIMH) 
  - dc11は実装していないので，'enable multiuser'は省略しました．(mkconfには入れました．)
  - rk2で'bad free count'というエラーが出ますが，simhでも出るので気にせずそのまま．
- rk0, rk1, rk2からsd用のイメージsd.dskの作成，書き込み手順は下記の通り．
```
dd if=/dev/zero of=sd.dsk bs=512 count=1024
dd if=rk0 of=sd.dsk bs=512 seek=1024 conv=notrunc
dd if=rk1 of=sd.dsk bs=512 seek=7168 conv=notrunc
dd if=rk2 of=sd.dsk bs=512 seek=13312 conv=notrunc

sudo dd if=sd.dsk of=/dev/sdb (sdメモリが/dev/sdbで正しいかちゃんと確認すること)
```
- sdメモリのブロックとの関係は下記の通り．
  - block0〜1023はrf0用です．(V6では使いませんが，V1との互換性を考慮しました．)
```
SD memory block (512byte/block)
         0-1023: rf0 (1024 block/drive)
      1024-7167: rk0 (6144 block/drive (=256cyl*2sur*12sectors))
     7168-13311: rk1
    13312-19455: rk2
    19456-25599: rk3
    ...
```

## 既知の問題
- ccを起動すると，'Can't find /lib/c0' となります．lsでは見えるのですが．15KBあるので，メモリが足りなくてロードできないという可能性があるかも． → simh 64K MEM でも同様らしいです．
- power on時に，DCJ11からABORT_nがパルス状に出力され，デバッグ情報のログに大量に出ます．INITでも収まらないので，構わず174000gで起動すればいいようです．~~次のリリースでbus_error信号を見るように修正します．~~ → 20240730a.v6.betaが修正版です．
- 放置しているだけでtrap&panicで終了することがあります．

## 更新履歴
- 2024/07/28: 0728.beta
  - 160000番地readでbus error．(V6実験用)
- 2024/07/29: 0729.v6.beta
  - unix-v1とunix-v6のフォルダを分離．
  - ABORT_nをトライステート化．
  - RAM 30MW化．bus errorの条件変更．(170000番地readでbus error)
- 2024/07/30: 0730.v6.beta
  - 複数disk drive(rk0, rk1, rk2, rk3,...,rk7)に対応．
- 2024/07/30: 0730a.v6.beta
  - デバッグログをabortではなくbus errorに修正
- 2025/09/06: HALTのジャンパを抵抗からダイオードに修正

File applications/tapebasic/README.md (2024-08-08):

# TangNanoDCJ11MEM (tapebasic)
  - 二次記憶をエミュレートするために手始めに作った習作です．
  - PC11(tape reader/pucnch)エミュレータで，tape BASICを読み込んで起動します．
  - SDメモリを使う練習用に作ったものなのでとりあえず動きます程度のものです．
  - unix-v1環境用のIRQやEVENT_nのジャンパ配線があると起動しないので外して下さい．
  - UART部分のコードが古いので文字化けすることがあります．ベアメタル版と同じ修正をすると安定すると思いますが動作確認が面倒なのでやってません．
  - PDP11GUIに，console ODT経由でpaper tape softwareをロードする機能があるようなので，いろいろなpaper tape softwareを試すという目的であればベアメタルでPDP11GUIを使うことをお勧めします．

## PC-11(Paper-Tape Reader/Punch)エミュレータ [sdtape.v](TangNanoDCJ11MEM_project/src/sdtape.v)
- SDメモリに入れた紙テープのイメージを読み込むエミュレータです
- SDメモリはファイルシステム無しの生のままで使うのでddで読み書きします．
- パンチ機能については，BASICのSAVEで書き込むことができたのでとりあえず動いているようですがまだバグがあると思います．(SAVEコマンドの後に，SW2でflushします．)
- とりあえず2GBのSD(SanDisk), 16GB, 32GBのSDHC(kioxia), 64GのSDXC(SAMSUNG)で動作しました．

使用例:
- [Paper Tape Archive](https://www.vaxhaven.com/Paper_Tape_Archive)から
absolute loader('ABSOLUTE-BINARY-LOADER.ptap')と，Paper Tape BASIC ('DEC-11-AJPB-PB.ptap')を入手し，sdメモリに書き込みます．(頭の000があると読めないようで，先頭の16byteを削除しました．)
- /dev/xxx は生のsdメモリの場所です．(先頭のブロックから書くので数字が付いてないやつ．'fdisk -l'等で調べて下さい．)
- 間違えるとパソコンの他のファイルシステムを破壊するので厳重に注意して行って下さい．

```
cat ABSOLUTE-BINARY-LOADER.ptap DEC-11-AJPB-PB.ptap | dd of=tapeimage.dat bs=1 skip=16
dd if=tapeimage.dat of=/dev/xxx
```
- TangNano20KのSDメモリスロットに入れて電源を入れ，ODT consoleから下記のように
してBASICが起動できます．

```
@37744g   ←bootstrap loader起動してabsolute loaderを読み込む
037500
@37500g   ←absolute loaderを起動してBASICを読み込む
PDP-11 BASIC, VERSION 007A
*O
READY
```

# 動画
- [PDP-11 Paper-Tape BASIC running on DCJ-11 Processor](https://www.youtube.com/watch?v=F_eFMz5ysK8)

# 更新履歴
- 2024/6/28: tapeimage.datの作成方法を修正

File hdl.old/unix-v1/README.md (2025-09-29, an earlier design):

# TangNanoDCJ11MEM (unix-v1)
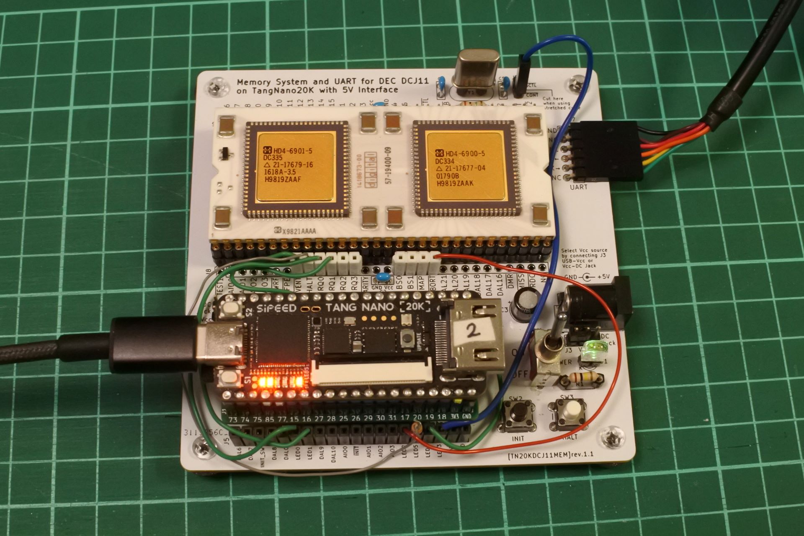
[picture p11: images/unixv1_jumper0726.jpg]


- TangNano20K上にPDP11用のメモリシステムや周辺装置を実装してUNIX first edition (UNIX V1)を動作させる試みです．
- まだかなり不安定で，ちょっと修正しただけで起動しなくなるのですが，とりあえず公開することにしました． ~~それなりに安定して動くようになりました．~~ やっぱりまだ不安定です．
- ~~DMAの制御が面倒だったので、時分割された擬似dual port RAMを作ってディスクからメモリへの読み書きをしています．~~
- ディスク読み書き時にstretched cycleでCPUを停止させることにしました．ピンが足りないので，DMR_n，MAP_nを使わずに，CONT_nだけで停止させてDMAしています．これによりだいぶ安定しました．JP1の切断と，LED3からCONT_nへのジャンパ接続が必要です．

## 最近の話題
### 2024/07/29 (0729.beta版公開)
  - UNIX V6に必要な機能を逐次追加していますが，修正のたびにV1の動作確認をするのが面倒なので別のバージョンとしてこちら [unix-v6](../unix-v6/) に置くことにしました．
  - メモリを30KWにしました．
  - ABORT_nをトライステートにしました．(UNIX V1では使用してないので気にしなくていいです．)

## TangNano20K上に実装したもの
- メインメモリ
  - 32K word (64k byte)．(000000〜167777の30KWがRAM，170000〜177777はROMとI/O)
- UART
  - USBとGPIOの2系統．通常はUSBがコンソールでGPIOはデバッグ情報を出力．
- ASR-33 (teletype)
  - UARTを使ったconsole機能(レジスタと割り込み)
- RF11(drum), RK11(disk)
  - ハードディスク装置をSDメモリでエミュレートします．
- KE11-A(Extended Arithmetic Element)
  - 外部演算装置です．UNIX V1では乗除算，シフト演算をCPUではなくこの装置で実行していることがあるので必須です．(diskのブロック計算で12で割る程度の計算をこれにやらせています．．．)
- KW11-L(Line time clock)
  - EVENT端子経由で60Hzの割り込みを発生させます．

## SDメモリによるディスク(RF，RK)のエミュレーションについて
 - SIMH用のimageファイルを継げたものを利用できます．(下記手順参照)
 - SDメモリはファイルシステム無しの生のままで使うのでddで読み書きします．
 - ブロックサイズ(BS)は512で，0〜1023ブロックがRF11，それ以降がRK11です．
 - SanDiskのsd(2GB)，KIOXIAのsdhc(32GB)，sdxc(64GB)での動作を確認しています．

## とりあえず動かすための手順
### JP1の切断
レジストの色によってはわかりにくいですが，基板右上にあるJP1の端子(SCTL_n と CONT_n)はパターンで接続されています．Stretched cycleを使用するため，これをカットします．(今となっては最初から切断してピンヘッダを立てるようにした方がスマートでしたが，当初はもしかしたら使うかも程度に思っていたので．)
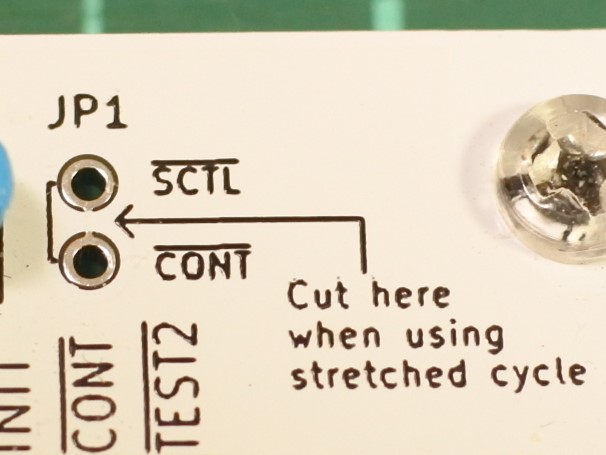
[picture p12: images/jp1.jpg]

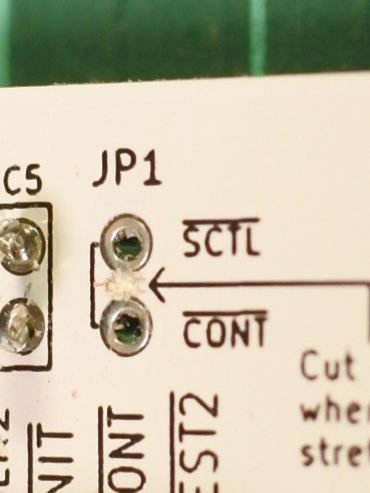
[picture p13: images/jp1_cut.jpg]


### ジャンパ配線等
- ~~クロック用の水晶を4MHzにする~~ 0716.betaから18MHzでも動作するようになりました。ちなみに2MHzでも動いています．

- IRQ、EVENT、CONT_n用に下記ジャンパ配線をする。HALTはデバッグ用なので任意。HALTはスイッチと競合するので~~1kΩの抵抗~~ダイオードを付けます。(1kΩ抵抗よりダイオード(1N4148等)の方が良さそうです．DCJ11側がカソードです．)
```
DCJ11       TangNano5V
IRQ0    --- LED0  (ttyi, ttyo用)
IRQ1    --- LED1  (drum, disk用)
EVENT_n --- LED4  (clock用)
CONT_n  --- LED3  (stretched cycle用)

HALT    ---K(1N4148)A--- LED5 (デバッグ用, 無くても可)

```
### SDメモリの準備
- [jserv/unix-v1](https://github.com/jserv/unix-v1) にあるsimh用のunix-v1環境一式をmakeし， images/rf0.dsk, images/rk0.dsk からsd用のイメージsd.dskを作り、sdメモリに書き込む。
- 参考手順は下記の通り。
  - /dev/xxx は生のsdメモリの場所です．(先頭のブロックから書くので数字が付いてないやつ(/dev/sdb など)．'fdisk -l'等で調べて下さい．) 間違えるとパソコンの他のファイルシステムを破壊するので厳重に注意して行って下さい．
```
git clone https://github.com/jserv/unix-v1.git
cd unix-v1
make
dd if=images/rf0.dsk of=sd.dsk
dd if=images/rk0.dsk of=sd.dsk bs=512 seek=1024
sudo dd if=sd.dsk of=/dev/xxx
```

## コンソール出力やポートについて
- TangNanoのUSB UART
  - DCJ-11のコンソール入出力とFPGAへの書き込みに使用します．
  - windows環境でTangNanoをUSB接続し，TeraTermでコンソール表示しながらビットストリームを書く場合，Gowin ProgrammerでUSB Debugger Aのポートが複数出現するので，プルダウンメニューで適切なものを選ぶ必要があります．
- GPIO UART
  - `define USE_GPIOUART_DEBUG が有効 → デバッグ情報(下記参照)が出力されます．
  - `define USE_GPIOUART_DEBUG をコメントアウト → Tang NanoのUSB UARTと同じものが出力されます．(起動しなくなることがあります．)
  - 入力はUSBとandで継げているので，速度が同じ場合はGPIO入力もコンソール入力になります．
- USBのシリアルとGPIOのシリアルはTeratermでシリアルポートを適切に選択すれば同時に見れます．
- シリアルの設定は115200bps,8N1Nです．(UNIX V6だと7N1Nにしないと文字化けする現象あり．)(速度はtop.vで変更可ですが，起動しなくなることがあります．)

## boot loaderについて
- simh版のboot loaderは73700番地に配置されていましたが，そこはRAM領域だし，オリジナルの資料によると173700のROM領域にあったので173700に配置しました．
- Power up configuration では1000番地単位にしか飛べないので，173000番地にPS=340とjmp 173700を置いてあります．
- INIT時に読み込まれる Power up configuration をTang NanoのSW2で選択するようにしました．
  - SW2を押さずにINIT: console ODTが起動します．
  - SW2を押しながらINIT: 173000番地から起動します．
  - console ODTからブートするには 173000g と入力して下さい．
- ~~ROM領域は書き込み禁止にはしてないので，上書きされる可能性があります．その場合はconsole ODTでboot.txtの手順で書き込むか，TangNanoを再起動してメモリを初期化します．~~ ROM領域は書き込み不可にしました．

## デバッグ用の機能について
- デバッグ用の機能をいくつか実装しています．詳細はtop.vを見て下さい．
### disk accessログ
- top.vの `define USE_GPIOUART_DEBUG を有効にすると使えます．
- GPIOのUARTにディスクアクセスに関する情報を出力しています．
  - 100μ秒のカウンタ，ディスク関連レジスタ，最後に読んだ命令のアドレスなどを表示しています．
### ブレークポイント
- デバッグ用レジスタDBG_REG0〜2(177100, 177102, 177104番地)に書いたアドレスの命令をフェッチしたときにHALT信号を出力する機能です．トリガ条件は下記の2種類があります．
  - (address == DBG_REG0 )
  - (address == DBG_REG1 ) の後に(address == DBG_REG2 )
- ~~address == 01040 (panic:)でもHALTするようにしています．~~ 

### 命令ログ
  - 177000〜177056番地に，HALTする直前にフェッチしていた命令のアドレスを24個記録しています．原因不明のHALTが起きたときの解析用です．(プリフェッチしているので，実行ではなくフェッチです．時系列は177000→177056の順．バージョンによっては個数が違う場合あり．詳細はソース参照．)

## 既知のノウハウ
- single user modeの方が起動しやすいです。177570番地の値を73700にして起動するとsingle user modeになります。
- 過去に起動した環境で起動しなくなったようなときは、sdメモリのディスクイメージが破壊されている可能性があるので、sd.dskに書き直します。
- 起動しにくい状態になったときは，ビットストリームをロードした直後の方が起動しやすい気がします．
- HALT SWで止めてレジスタやメモリを見たあとに p でUNIXに戻れます．(console ODTの機能)
- 予期せぬHALTで停止したときは，命令ログ(177000〜177056番地)，R0〜R7，スタックポインタ(R6)周辺の±8ワードぐらいをダンプして観察するのが初手です．スタックポインタがずれてたり，値がおかしくて変な番地にリターンしてHALTすることが多いです．

## 既知の問題
- 20240719版以降でだいぶ安定しました．クロック18MHz(2MHzでもOK)，デバッグ出力あり(無しでもOK)で，cコンパイラがわりと安定して動作しています．
- ~~時間制約(sdcファイル)の記述がよくわからないので，sys_clk=27MHzだけしか記述していません．そのせいかタイミングのwarningが多数出ます．~~
- sys_clk=27MHzだけだと起動しなくなる現象が発生しやすいので，ALE_nとSCTL_nも4.5MHzで適当な位相で書いてあります．正しい書き方は不明です．
- GPIOのデバッグ情報出力の有無を変更するとUNIXが起動しなくなる場合があり，時間制約を適当に修正すると起動することがあります．
- 起動しなくなる現象はdisk完了のIRQが出ていないのが主な原因だったっぽいのでdisk_readyのロジックを修正して少しはマシになりましたが完治はしていません．雑な修正(dirty workaround)です．
- UNIX V6は起動しません．
- デバッグログのIRQ_ttyi, IRQ_ttyoの判定条件がvec_readではなくbus_readになっているので割り込み以外でベクタの番地を読んだときも表示されます(0727.beta)．次版で修正します．

## 過去の問題
- ~~login時に000056や00002でHALTすることがあります．どうやらスタックポインタが1ワードずれているのが原因のようで，現在調査中です．~~
- ~~login時にpasswdファイルが読めないというエラーが起きることがあります．~~
- ~~root dir (/) が読めない状態になることがあります．(その際，コマンドは'No command'になります．) 000051(/のinode番号)であるはずのrootdir(25246番地)が000041や000050に化けていることが原因ですが，化ける原因についてはまだわかっていません．~~
- ~~HALTでなく，idle状態で止まることもあります．diskやttyの終了割り込み関連な気がしますが調査中です．~~ たぶん割り込みが発生しないのでidleのwait命令で止まっている．
- ~~とにかく不安定です． 起動したりしなかったりします．よく落ちます．~~
- ~~リセット時間を250msから350msに変えただけで起動しなったりします。~~
- ~~UARTの速度を変えただけで起動しなかったりします．~~ 対処しました．
- ~~UARTが不安定で文字化けします．~~ 対処しました．
- ~~論理合成時に，logical loopがあるというwarningが大量に出ます．除算器の部分なのですが，特に問題は無いはずなので放置しています．~~ 非同期SR付きDFFが合成できないというのが原因のようだったので修正しました．
- ~~論理合成時に，タイミング関連で警告が大量に出ているのですが，対処方法調査中です．不安定なのはこのあたりが原因かもしれません．~~ 一応対処しました．
- ~~0710.alphaでRF,RKの制御を大幅に修正し，/usrディレクトリ(RK)でmkdirができるようになりましたが，あいかわらず不安定です．~~ 0712.alphaで解消
- ~~/usrディレクトリ(RK)でcpするとHALTすることがあります．~~ 0712.alphaで解消

- SCTL_n，ALE_nのエッジ検出の実装方法を変えると起動しなくなることがあります．たぶんこれも時間制約がらみな気がします．
- 20240719.beta版で，1040番地でHALTする部分をコメントアウトすると起動しなくなりました．時間制約を下記のように修正すると起動するようになりました．次回リリースで修正します．
```
create_clock -name sys_clk -period 37.037 -waveform {0 18.518} [get_ports {sys_clk}]
create_clock -name ALE_n -period 222.222 -waveform {0 100} [get_ports {ALE_n}]
create_clock -name SCTL_n -period 222.222 -waveform {33.33 166.666} [get_ports {SCTL_n}]
```
## 動画
- [UNIX V1 on DEC DCJ-11 with TangNano 20K (under development)](https://www.youtube.com/watch?v=DT7xJWeF46Y)

- [UNIX V1 on DEC DCJ-11 with TangNano 20K](https://www.youtube.com/watch?v=G9AFgAaTexo)

## 更新履歴
- 2024/06/28: テスト用バージョン(TangNanoDCJ11MEM_project.0628.alpha)暫定公開．GPIOのUARTにディスクアクセスの情報を出力します．
- 2024/07/04: テスト用バージョン(0704.alpha)upload．
- 2024/07/07: テスト用バージョン(0707.alpha)upload．
- 2024/07/09: テスト用バージョン(0709.alpha)upload．
- 2024/07/10: テスト用バージョン(0710.alpha)upload．RFとRKのコマンド受付を並列化しました．
- 2024/07/12: テスト用バージョン(0712.alpha)upload．命令ログ機能追加．diskログ機能用のフラグ(`define USE_GPIOUART_DEBUG)はコメントアウトしました．
- 2024/07/13: テスト用バージョン(0713.alpha)upload．IRQ関連を修正．命令ログ拡張．
- 2024/07/14: テスト用バージョン(0714.alpha)upload．デバッグ用レジスタのアドレス等を変更．
- 2024/07/16: テスト用バージョン(0716.beta)upload．stretched cycle導入．JP1の切断と，LED3からCONT_nへのジャンパ接続が必要です．GPIO uartのデバッグログ機能をoffにすると起動しなくなるので，ONにしています．
- 2024/07/19: テスト用バージョン(0719.beta)upload．これまでに比べるとだいぶ安定しました．高速18MHz/低速2MHz， デバッグログあり/無し，のいずれでもcコンパイラが動作しています．
- 2024/07/26: テスト用バージョン(0726.beta)upload．(いろいろ不備が見つかったのでキャンセルしました．)
- 2024/07/27: テスト用バージョン(0727.beta)upload．
  - disk_ready logicの安定化．
  - uart.vのTXにバッファを付けたので文字出力が高速になりました．低速動作も110bpsまで動作するように修正しましたが，TangNanoのUSBシリアルは最低1200bpsでした．
  - UNIX V6実験用の機能(ABORT_n, ROM領域, RKからのboot)を追加しました．
  - GPIOのシリアルはデバッグ情報出力をデフォルトにしました．オフにすると起動しなくなることがあります．
- 2024/07/28: oldフォルダが肥大化してきたので一部削除しました．
- 2024/07/28: テスト用バージョン(0728.beta)upload．160000番地readでbus errorにしました．(V6実験用)
- 2024/07/29: 0729.beta公開．unix-v1とunix-v6のフォルダを分離．
- 2025/09/06: HALTのジャンパを抵抗からダイオードに修正

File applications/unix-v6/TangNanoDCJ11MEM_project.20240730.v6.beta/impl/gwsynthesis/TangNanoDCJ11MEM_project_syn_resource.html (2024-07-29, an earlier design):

# Hierarchy Module Resource

MODULE NAME | REG NUMBER | ALU NUMBER | LUT NUMBER | DSP NUMBER | BSRAM NUMBER | SSRAM NUMBER | ROM16 NUMBER
top (C:/wks/ework/FPGA/TangNano/20k/TangNanoDCJ11MEM/github/TangNanoDCJ11MEM/applications/unix-v6/TangNanoDCJ11MEM_project.20240730.v6.beta/src/top.v) | 2270 | 247 | 4243 | 1 | 32 | - | -
|--integer_division (C:/wks/ework/FPGA/TangNano/20k/TangNanoDCJ11MEM/github/TangNanoDCJ11MEM/applications/unix-v6/TangNanoDCJ11MEM_project.20240730.v6.beta/src/top.v) | 2314 | 1093 | 298 | - | - | - | -
|--uart_rx_inst (C:/wks/ework/FPGA/TangNano/20k/TangNanoDCJ11MEM/github/TangNanoDCJ11MEM/applications/unix-v6/TangNanoDCJ11MEM_project.20240730.v6.beta/src/top.v) | 44 | 19 | 34 | - | - | - | -
|--uart_tx_inst (C:/wks/ework/FPGA/TangNano/20k/TangNanoDCJ11MEM/github/TangNanoDCJ11MEM/applications/unix-v6/TangNanoDCJ11MEM_project.20240730.v6.beta/src/top.v) | 62 | 21 | 99 | - | 1 | - | -
|--sdhd_inst (C:/wks/ework/FPGA/TangNano/20k/TangNanoDCJ11MEM/github/TangNanoDCJ11MEM/applications/unix-v6/TangNanoDCJ11MEM_project.20240730.v6.beta/src/top.v) | 396 | 98 | 590 | - | 1 | 2 | -
|--onboard_rgb_led (C:/wks/ework/FPGA/TangNano/20k/TangNanoDCJ11MEM/github/TangNanoDCJ11MEM/applications/unix-v6/TangNanoDCJ11MEM_project.20240730.v6.beta/src/top.v) | 45 | - | 82 | - | - | - | -
|--uart_tx_inst_dbg (C:/wks/ework/FPGA/TangNano/20k/TangNanoDCJ11MEM/github/TangNanoDCJ11MEM/applications/unix-v6/TangNanoDCJ11MEM_project.20240730.v6.beta/src/top.v) | 62 | 21 | 99 | - | 1 | - | -

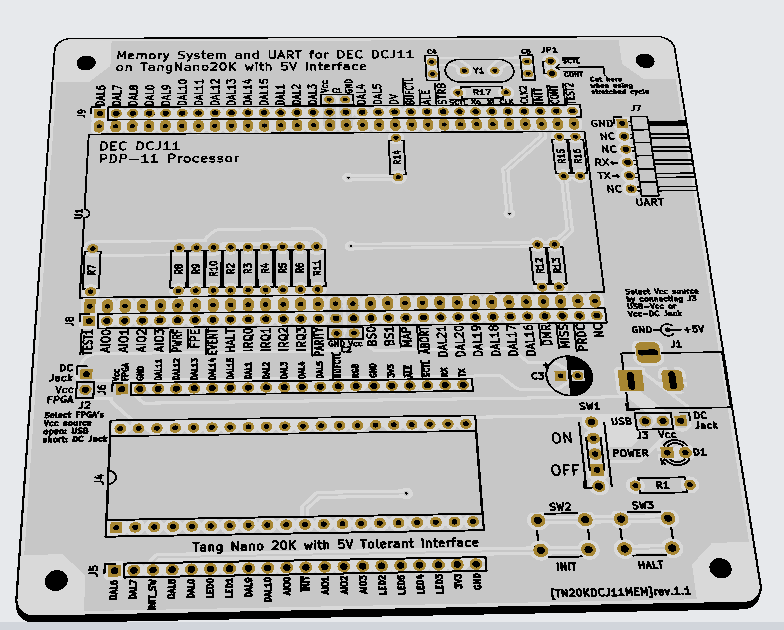
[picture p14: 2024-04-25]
images/rev11_3d.png

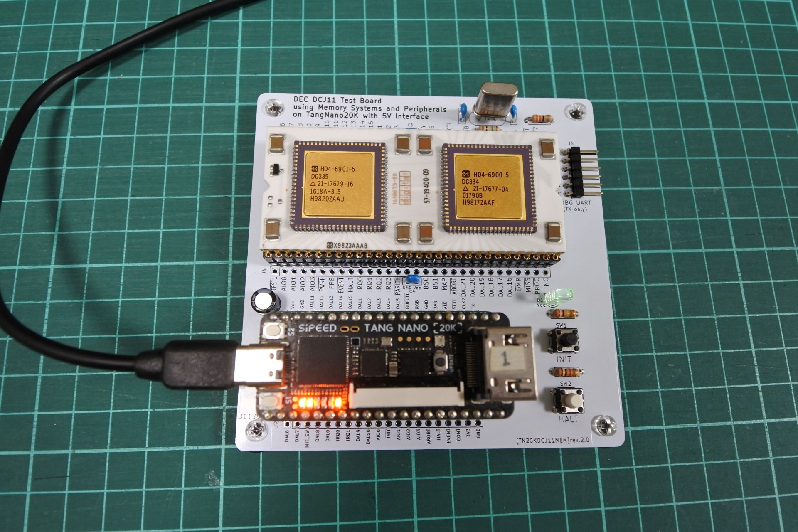
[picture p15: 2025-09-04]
images/rev20.jpg

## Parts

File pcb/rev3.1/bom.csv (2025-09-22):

Reference | Value | Datasheet | Footprint | Qty | DNP
C1,C2 | 68p | ~ | 000_MyFootprint:C_Disc_D5.0mm_W2.5mm_P2.50mm | 2
C3,C4,C5,C6 | 0.1uF | ~ | 000_MyFootprint:C_Disc_D5.0mm_W2.5mm_P2.50mm | 4
C7,C8 | 0.33uF | ~ | 000_MyFootprint:C_Disc_D5.0mm_W2.5mm_P2.50mm | 2
C9 | 47uF | ~ | 000_MyFootprint:CP_Radial_D6.3mm_P2.50mm | 1
D1 | 1N4148 |  | 000_MyFootprint:D_T-1_P5.08mm_Horizontal | 1
J1 | TangNano20K | ~ | 000_MyFootprint:DIP-40_W20.32mm800mil_Socket | 1
J2,J3 | Conn_01x30 | ~ | 000_MyFootprint:PinSocket_1x30_P2.54mm_Vertical | 2
J4 | Disable | ~ | 000_MyFootprint:JumperedPinHeader_1x02_P2.54mm_Vertical | 1
J5 | DBG UART | ~ | 000_MyFootprint:PinHeader_1x06_P2.54mm_Horizontal | 1
J6 | WS2812 | ~ | 000_MyFootprint:PinSocket_1x04_P2.54mm_Horizontal | 1
LED1 | LED | ~ | 000_MyFootprint:LED_D3.0mm | 1
R1 | 1M | ~ | 000_MyFootprint:R_Axial_DIN0207_L6.3mm_D2.5mm_P7.62mm_Horizontal | 1
R2 | 33 | ~ | 000_MyFootprint:R_Axial_DIN0207_L6.3mm_D2.5mm_P7.62mm_Horizontal | 1
R3,R4,R5,R6,R7,R8,R9,R10,R11,R12,R13,R14,R15 | 10k | ~ | 000_MyFootprint:R_Axial_DIN0207_L6.3mm_D2.5mm_P7.62mm_Horizontal | 13
R16 | 100k | ~ | 000_MyFootprint:R_Axial_DIN0207_L6.3mm_D2.5mm_P7.62mm_Horizontal | 1
SW1 | INIT | ~ | 000_MyFootprint:SW_PUSH_6mm_H4.3mm | 1
SW2 | HALT | ~ | 000_MyFootprint:SW_PUSH_6mm_H4.3mm | 1
U1 | DCJ11 |  | 000_MyFootprint:DIP-60_W33.02mm_LongPads | 1
U2,U3,U4,U5 | SN74CB3T3245DW | SN74CB3T3245DW | 000_MyFootprint:DW20 | 4
Y1 | 18MHz | ~ | 000_MyFootprint:Crystal_HC49-U_Vertical | 1

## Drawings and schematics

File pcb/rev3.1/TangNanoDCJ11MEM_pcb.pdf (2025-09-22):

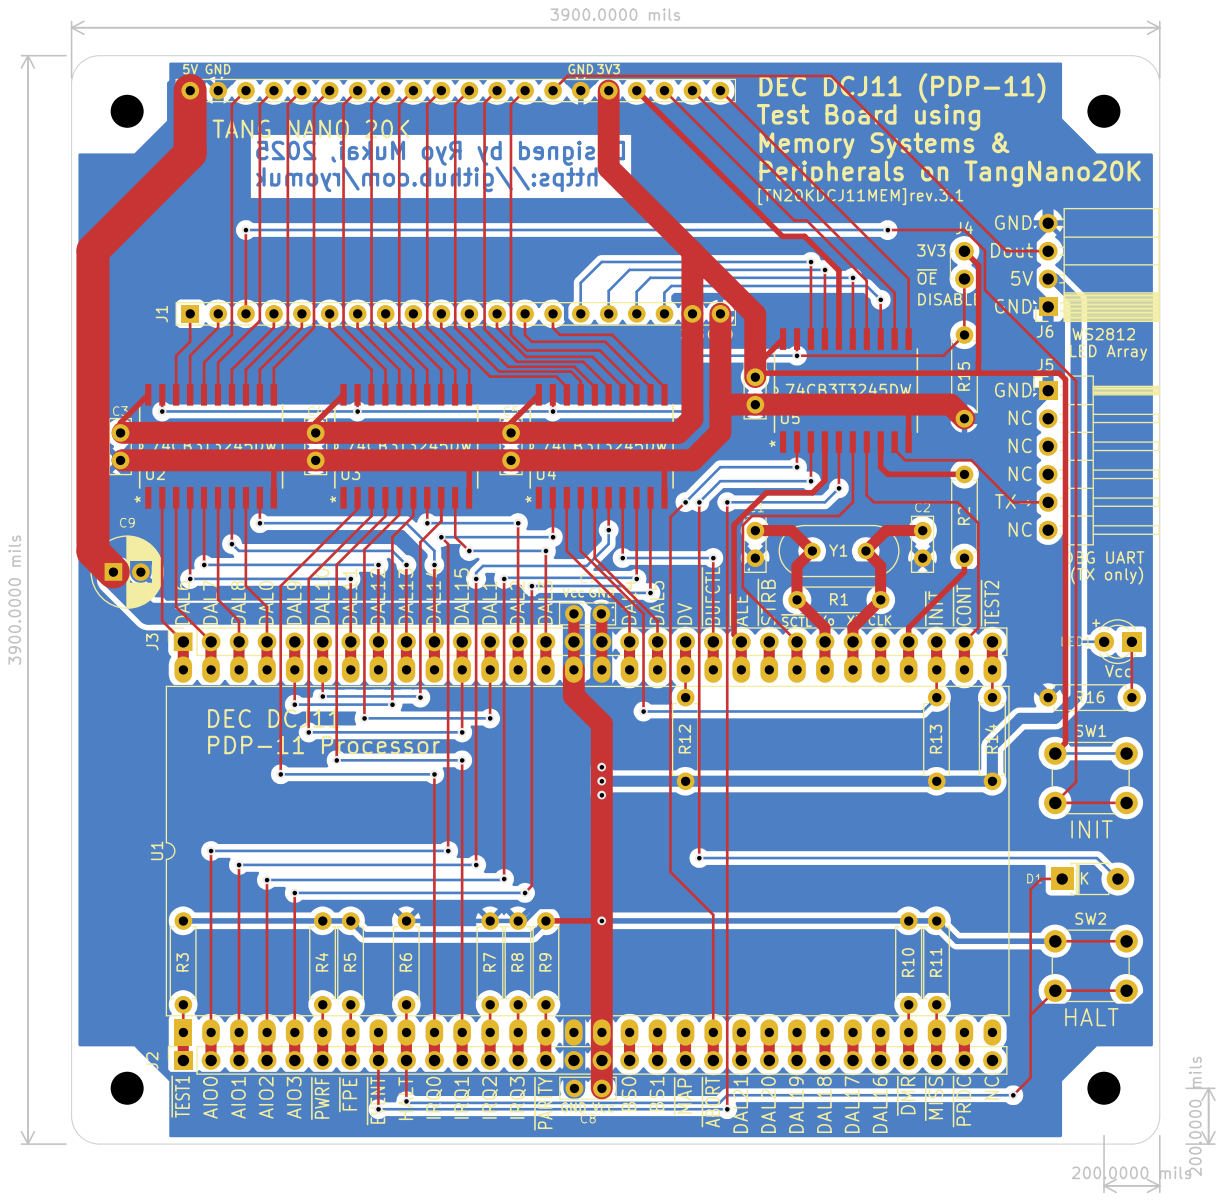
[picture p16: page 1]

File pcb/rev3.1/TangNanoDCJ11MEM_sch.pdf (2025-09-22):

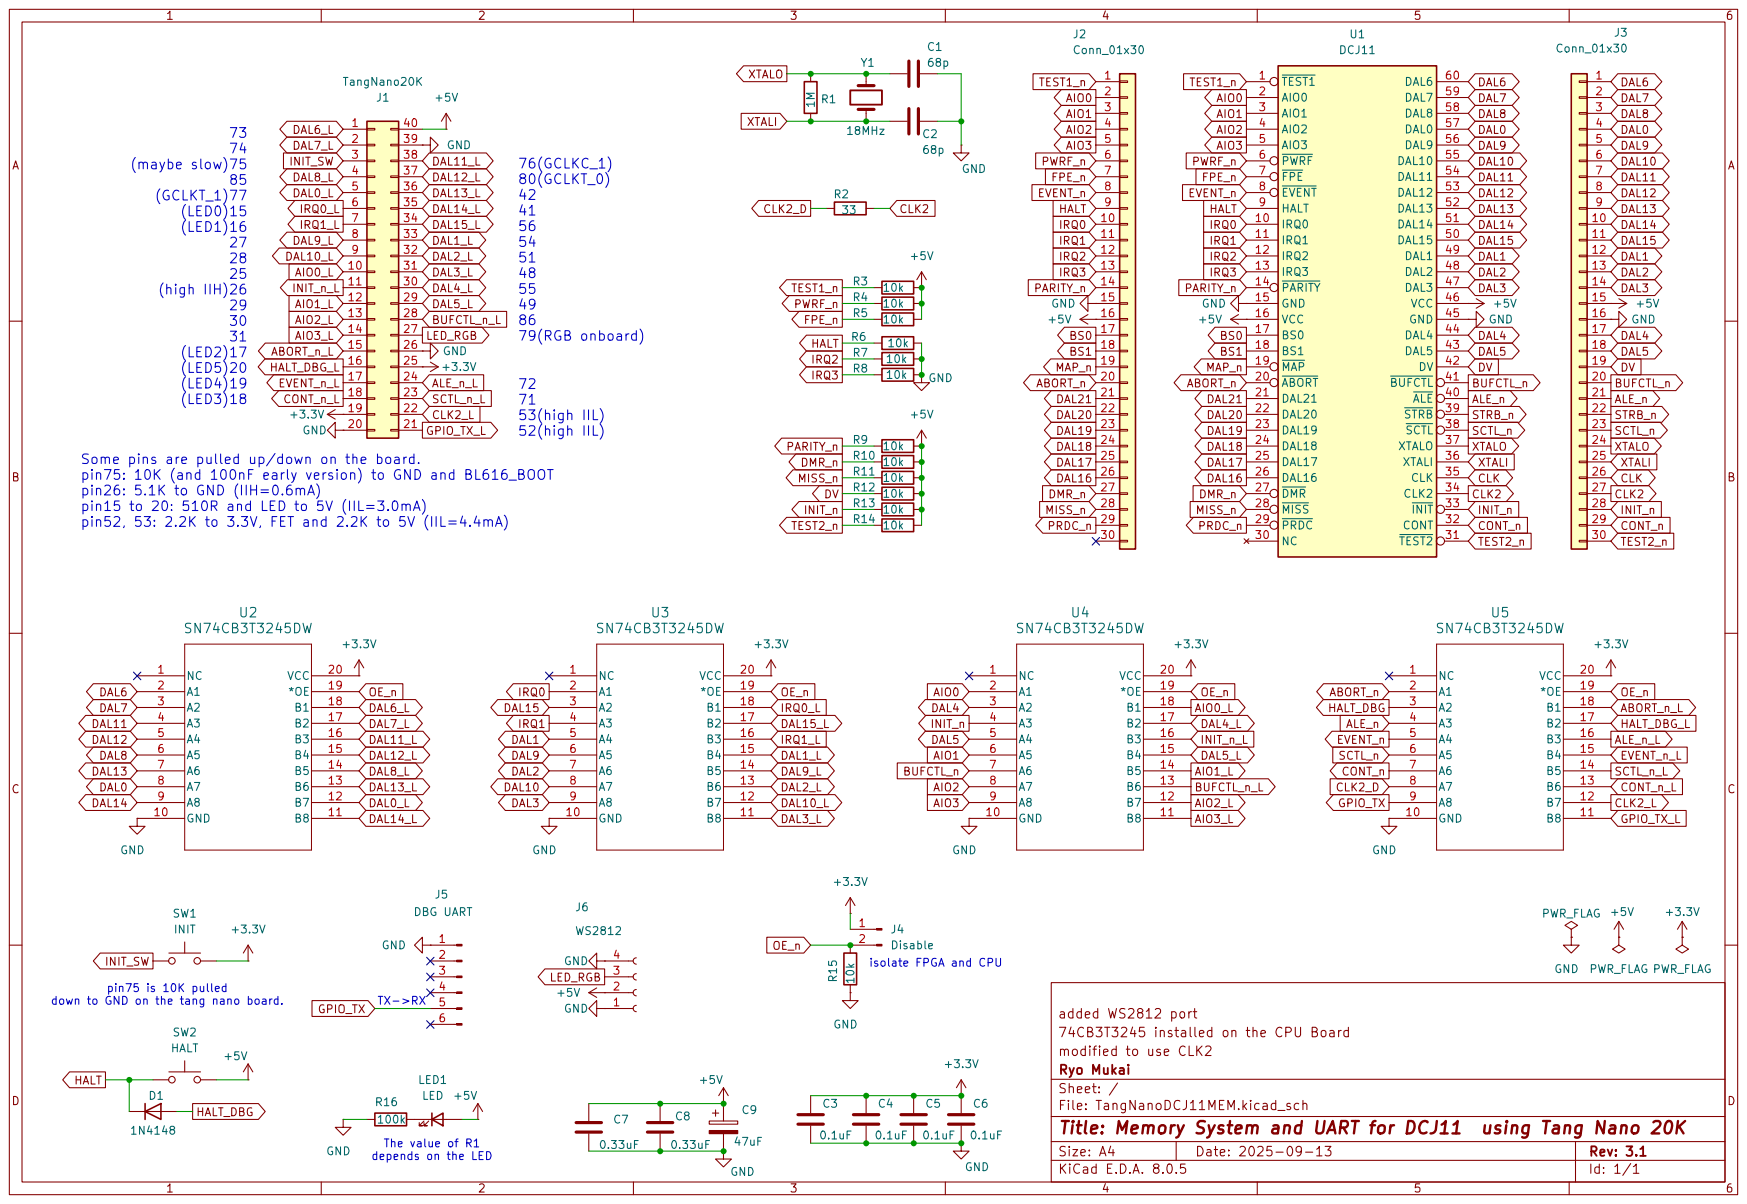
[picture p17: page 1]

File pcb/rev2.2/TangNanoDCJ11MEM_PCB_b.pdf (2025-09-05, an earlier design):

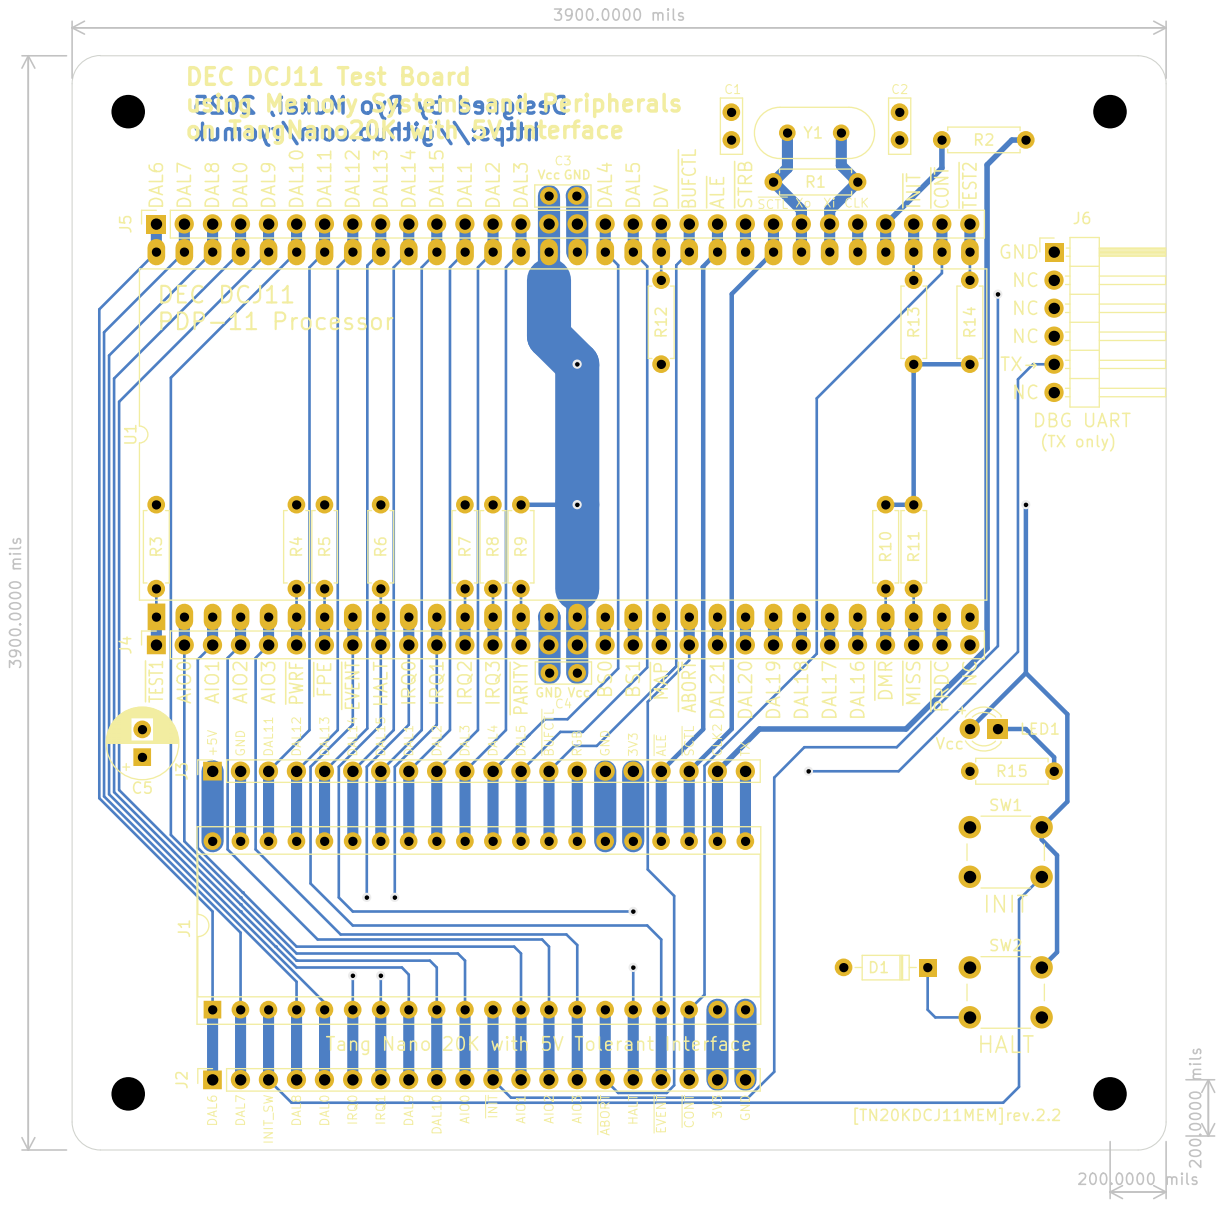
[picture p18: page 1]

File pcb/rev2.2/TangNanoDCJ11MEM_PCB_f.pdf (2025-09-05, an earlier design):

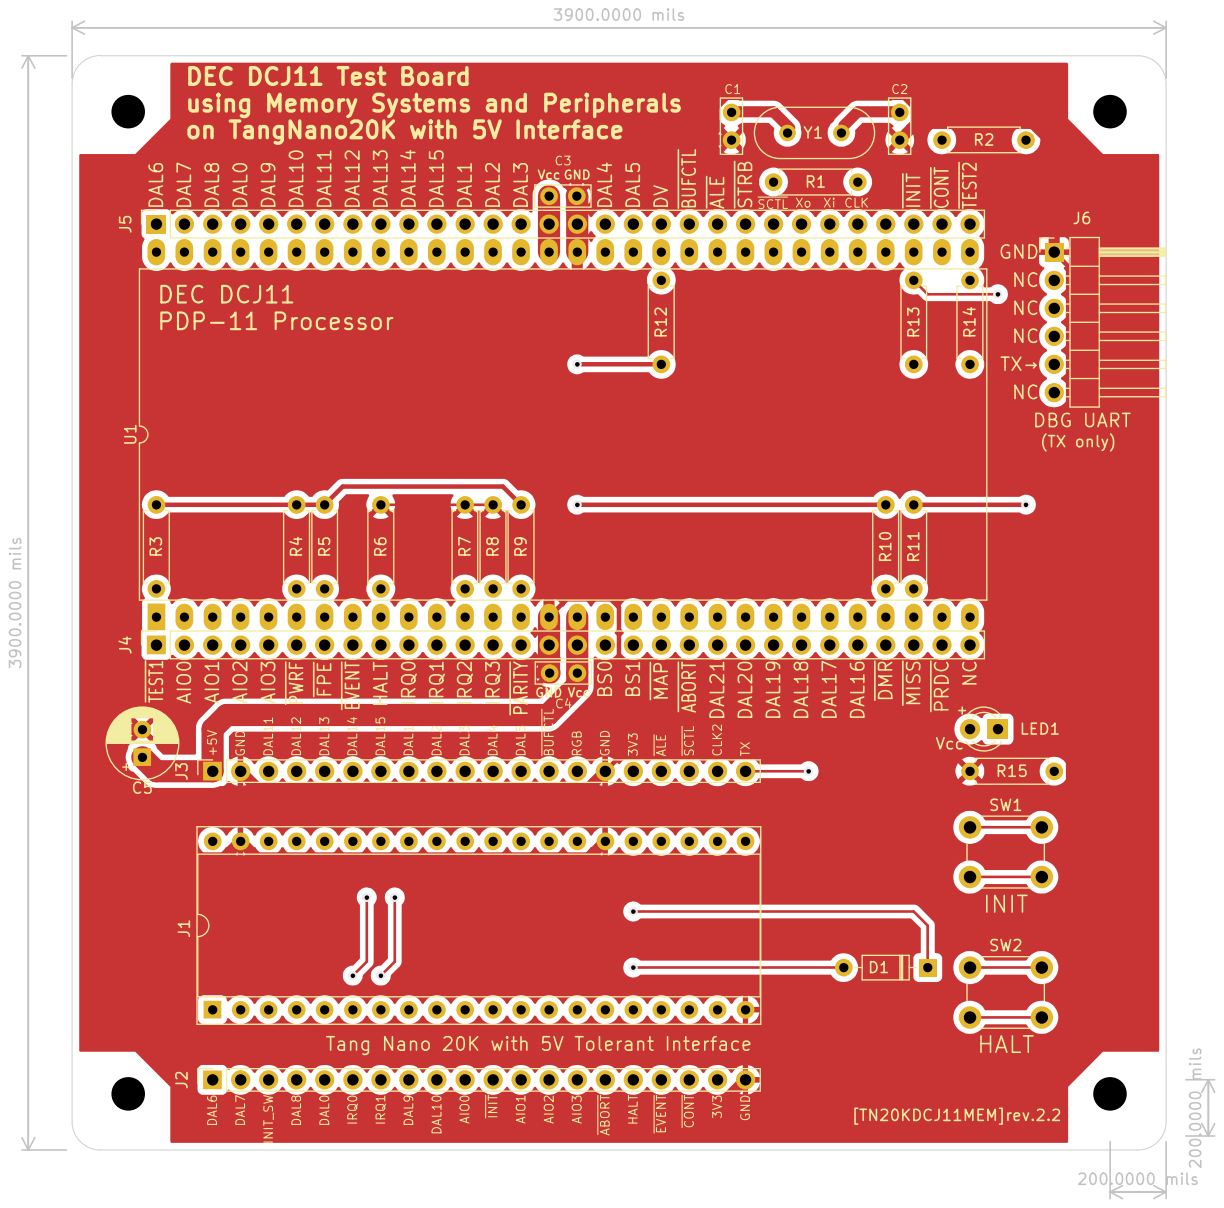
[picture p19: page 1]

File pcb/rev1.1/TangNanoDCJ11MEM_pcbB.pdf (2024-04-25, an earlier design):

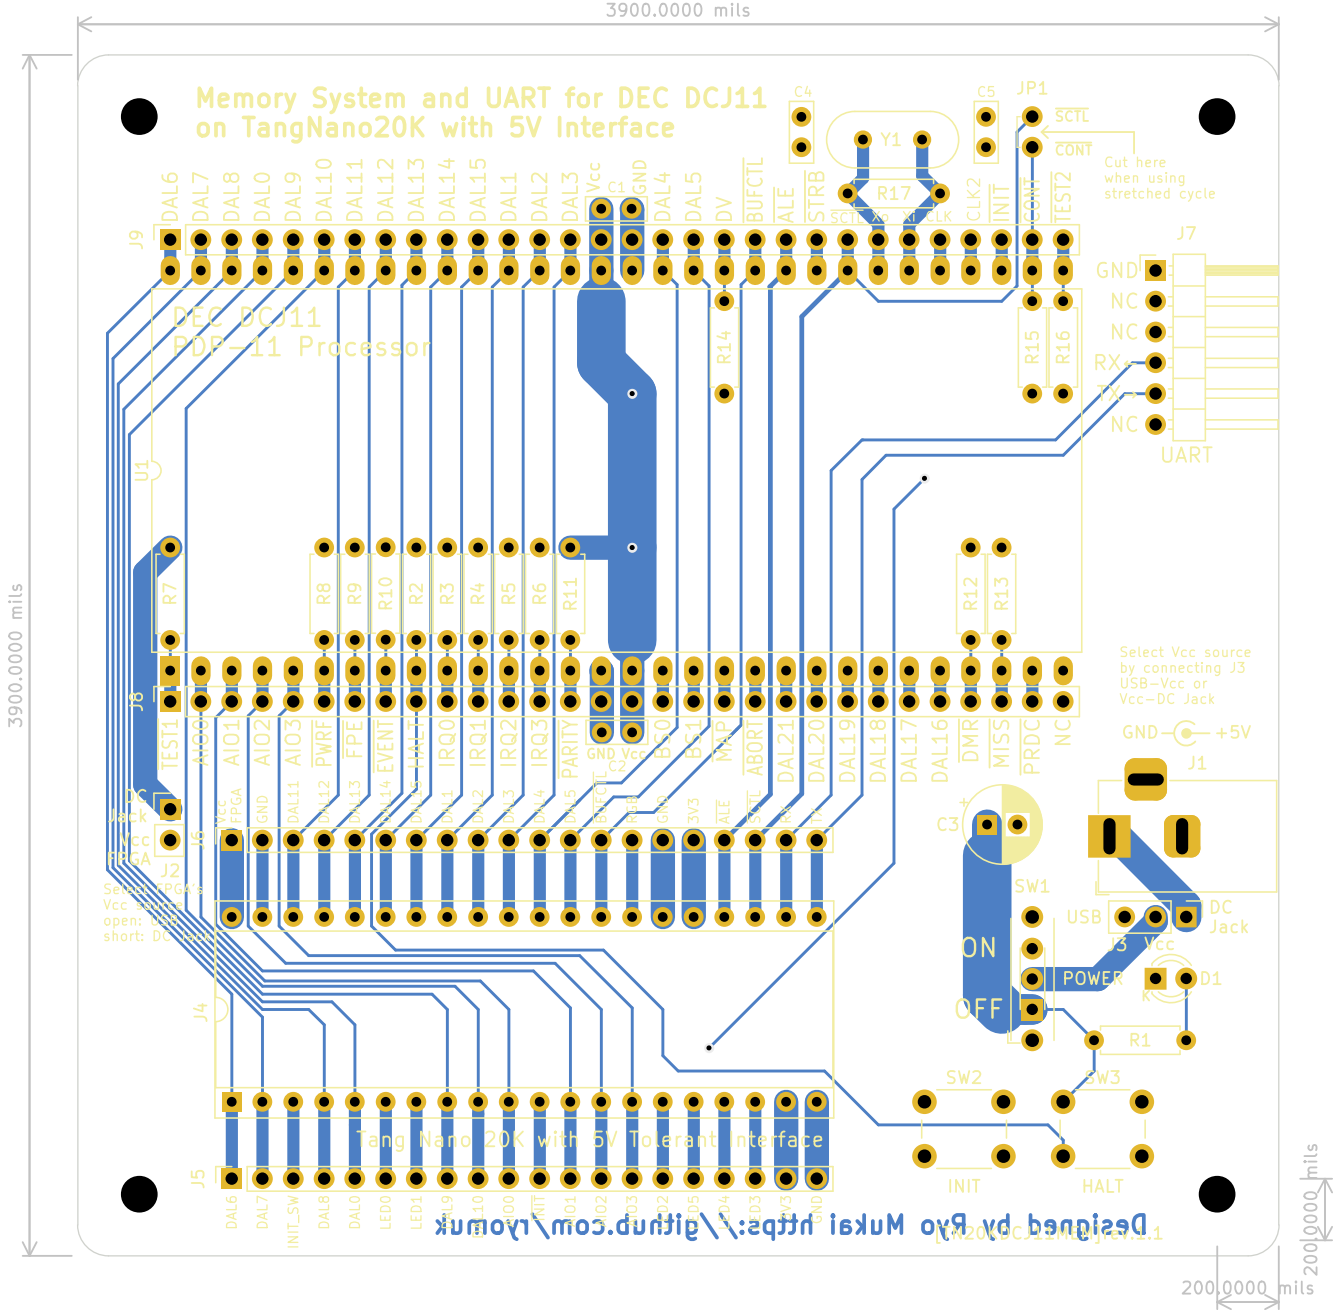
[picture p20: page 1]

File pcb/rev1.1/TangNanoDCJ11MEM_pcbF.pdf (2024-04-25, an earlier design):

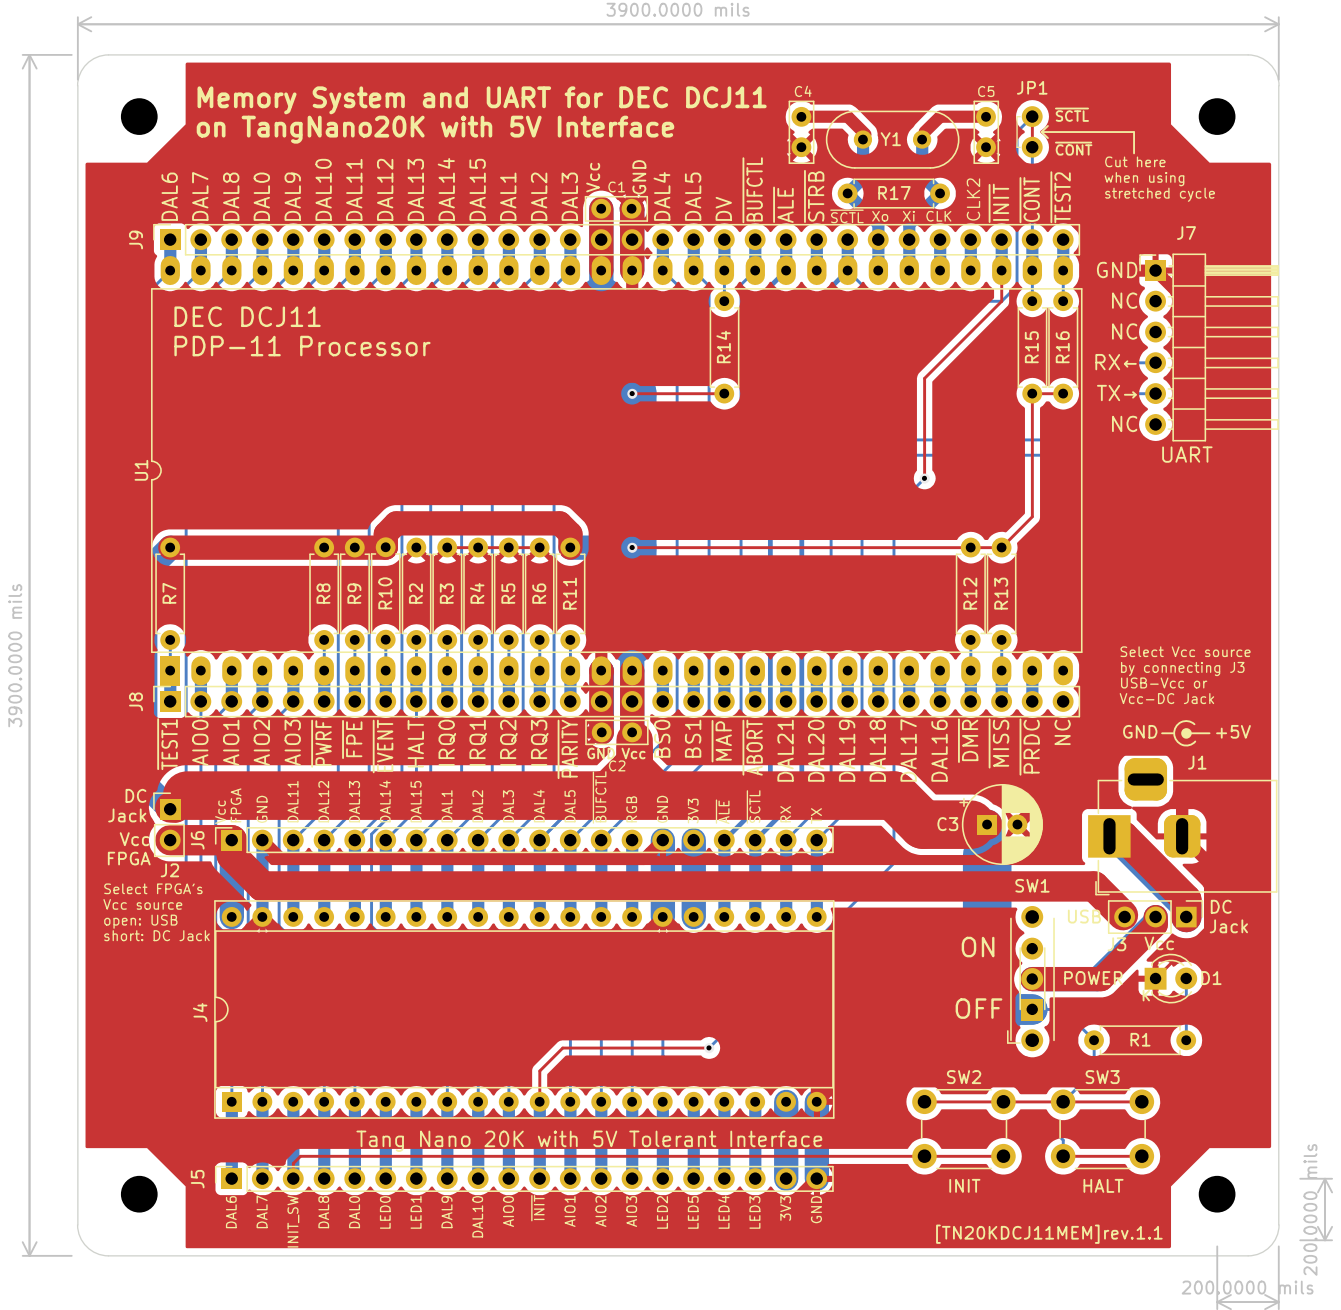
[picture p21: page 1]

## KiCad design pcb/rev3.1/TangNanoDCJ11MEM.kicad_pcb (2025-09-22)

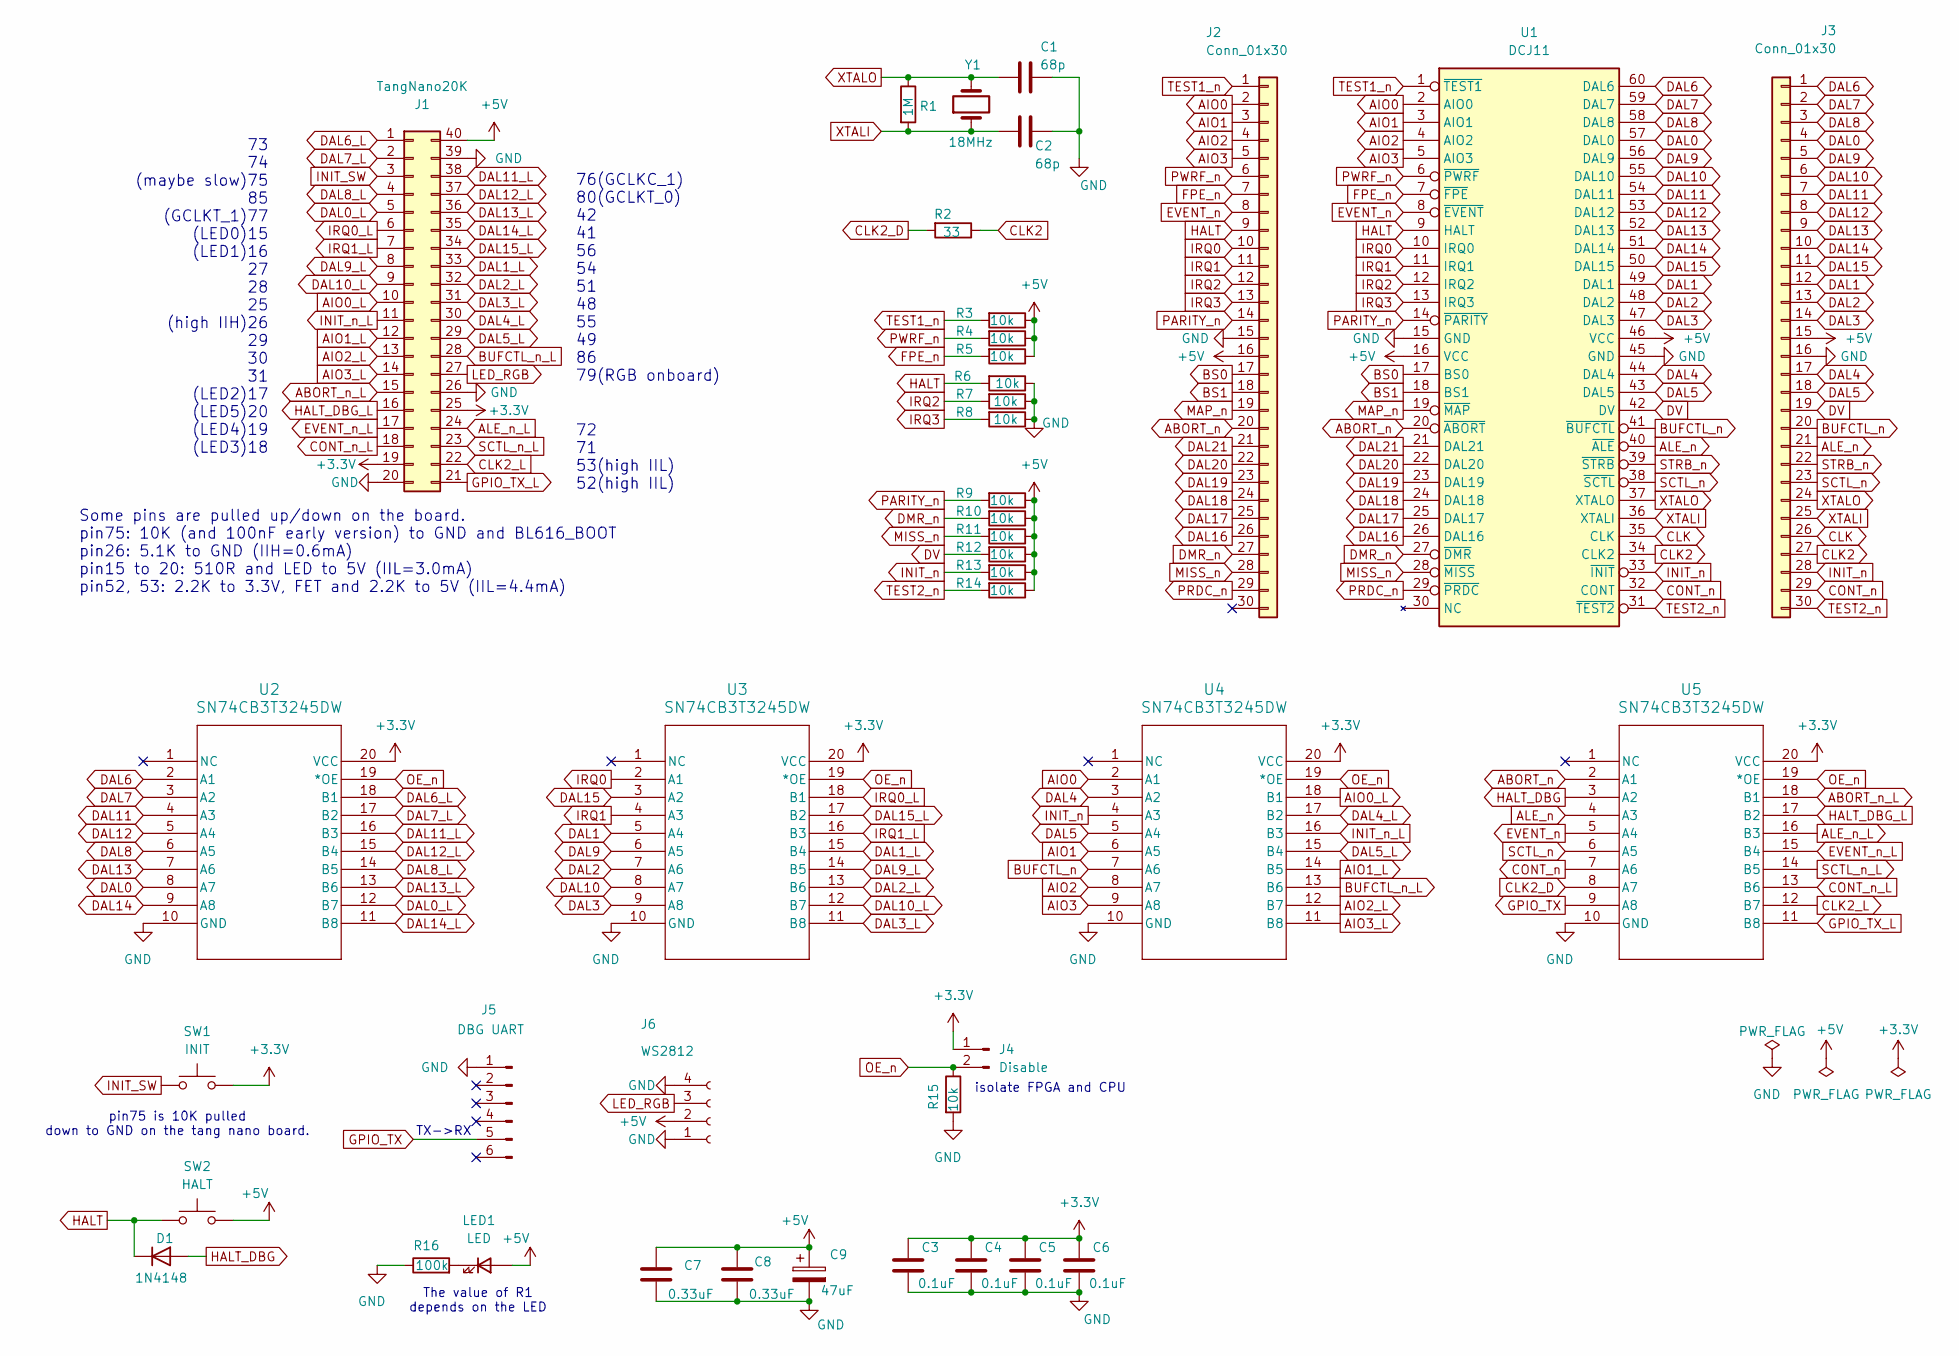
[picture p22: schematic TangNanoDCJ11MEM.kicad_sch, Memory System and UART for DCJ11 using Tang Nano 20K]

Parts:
C1, C2: 68p; C_Disc_D5.0mm_W2.5mm_P2.50mm
C3, C4, C5, C6: 0.1uF; C_Disc_D5.0mm_W2.5mm_P2.50mm
C7, C8: 0.33uF; C_Disc_D5.0mm_W2.5mm_P2.50mm
C9: 47uF; CP_Radial_D6.3mm_P2.50mm
D1: 1N4148; D_T-1_P5.08mm_Horizontal
J1: TangNano20K; DIP-40_W20.32mm800mil_Socket
J2, J3: Conn_01x30; PinSocket_1x30_P2.54mm_Vertical
J4: Disable; JumperedPinHeader_1x02_P2.54mm_Vertical
J5: DBG UART; PinHeader_1x06_P2.54mm_Horizontal
J6: WS2812; PinSocket_1x04_P2.54mm_Horizontal
LED1: LED; LED_D3.0mm
R1: 1M; R_Axial_DIN0207_L6.3mm_D2.5mm_P7.62mm_Horizontal
R2: 33; R_Axial_DIN0207_L6.3mm_D2.5mm_P7.62mm_Horizontal
R3, R4, R5, R6, R7, R8, R9, R10, R11, R12, R13, R14, R15: 10k; R_Axial_DIN0207_L6.3mm_D2.5mm_P7.62mm_Horizontal
R16: 100k; R_Axial_DIN0207_L6.3mm_D2.5mm_P7.62mm_Horizontal
SW1: INIT; SW_PUSH_6mm_H4.3mm
SW2: HALT; SW_PUSH_6mm_H4.3mm
U1: DCJ11; DIP-60_W33.02mm_LongPads
U2, U3, U4, U5: SN74CB3T3245DW; DW20
Y1: 18MHz; Crystal_HC49-U_Vertical

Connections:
+3.3V: C3.1, C4.1, C5.1, C6.1, J1.19, J1.25, J4.1, SW1.1, U2.20 (VCC), U3.20 (VCC), U4.20 (VCC), U5.20 (VCC)
+5V: C7.1, C8.1, C9.1, J1.40, J2.16, J3.15, J6.2, LED1.2 (A), R3.1, R4.1, R5.1, R9.1, R10.1, R11.1, R12.1, R13.1, R14.1, SW2.1, U1.16 (VCC), U1.46 (VCC)
ABORT_n: J2.20, U1.20 (~ABORT), U5.2 (A1)
ABORT_n_L: J1.15, U5.18 (B1)
AIO0: J2.2, U1.2 (AIO0), U4.2 (A1)
AIO0_L: J1.10, U4.18 (B1)
AIO1: J2.3, U1.3 (AIO1), U4.6 (A5)
AIO1_L: J1.12, U4.14 (B5)
AIO2: J2.4, U1.4 (AIO2), U4.8 (A7)
AIO2_L: J1.13, U4.12 (B7)
AIO3: J2.5, U1.5 (AIO3), U4.9 (A8)
AIO3_L: J1.14, U4.11 (B8)
ALE_n: J3.21, U1.40 (~ALE), U5.4 (A3)
ALE_n_L: J1.24, U5.16 (B3)
BS0: J2.17, U1.17 (BS0)
BS1: J2.18, U1.18 (BS1)
BUFCTL_n: J3.20, U1.41 (~BUFCTL), U4.7 (A6)
BUFCTL_n_L: J1.28, U4.13 (B6)
CLK: J3.26, U1.35 (CLK)
CLK2: J3.27, R2.1, U1.34 (CLK2)
CLK2_D: R2.2, U5.8 (A7)
CLK2_L: J1.22, U5.12 (B7)
CONT_n: J3.29, U1.32 (CONT), U5.7 (A6)
CONT_n_L: J1.18, U5.13 (B6)
DAL0: J3.4, U1.57 (DAL0), U2.8 (A7)
DAL0_L: J1.5, U2.12 (B7)
DAL1: J3.12, U1.49 (DAL1), U3.5 (A4)
DAL1_L: J1.33, U3.15 (B4)
DAL2: J3.13, U1.48 (DAL2), U3.7 (A6)
DAL2_L: J1.32, U3.13 (B6)
DAL3: J3.14, U1.47 (DAL3), U3.9 (A8)
DAL3_L: J1.31, U3.11 (B8)
DAL4: J3.17, U1.44 (DAL4), U4.3 (A2)
DAL4_L: J1.30, U4.17 (B2)
DAL5: J3.18, U1.43 (DAL5), U4.5 (A4)
DAL5_L: J1.29, U4.15 (B4)
DAL6: J3.1, U1.60 (DAL6), U2.2 (A1)
DAL6_L: J1.1, U2.18 (B1)
DAL7: J3.2, U1.59 (DAL7), U2.3 (A2)
DAL7_L: J1.2, U2.17 (B2)
DAL8: J3.3, U1.58 (DAL8), U2.6 (A5)
DAL8_L: J1.4, U2.14 (B5)
DAL9: J3.5, U1.56 (DAL9), U3.6 (A5)
DAL9_L: J1.8, U3.14 (B5)
DAL10: J3.6, U1.55 (DAL10), U3.8 (A7)
DAL10_L: J1.9, U3.12 (B7)
DAL11: J3.7, U1.54 (DAL11), U2.4 (A3)
DAL11_L: J1.38, U2.16 (B3)
DAL12: J3.8, U1.53 (DAL12), U2.5 (A4)
DAL12_L: J1.37, U2.15 (B4)
DAL13: J3.9, U1.52 (DAL13), U2.7 (A6)
DAL13_L: J1.36, U2.13 (B6)
DAL14: J3.10, U1.51 (DAL14), U2.9 (A8)
DAL14_L: J1.35, U2.11 (B8)
DAL15: J3.11, U1.50 (DAL15), U3.3 (A2)
DAL15_L: J1.34, U3.17 (B2)
DAL16: J2.26, U1.26 (DAL16)
DAL17: J2.25, U1.25 (DAL17)
DAL18: J2.24, U1.24 (DAL18)
DAL19: J2.23, U1.23 (DAL19)
DAL20: J2.22, U1.22 (DAL20)
DAL21: J2.21, U1.21 (DAL21)
DMR_n: J2.27, R10.2, U1.27 (~DMR)
DV: J3.19, R12.2, U1.42 (DV)
EVENT_n: J2.8, U1.8 (~EVENT), U5.5 (A4)
EVENT_n_L: J1.17, U5.15 (B4)
FPE_n: J2.7, R5.2, U1.7 (~FPE)
GND: C1.1, C2.1, C3.2, C4.2, C5.2, C6.2, C7.2, C8.2, C9.2, J1.20, J1.26, J1.39, J2.15, J3.16, J5.1, J6.1, J6.4, R6.1, R7.1, R8.1, R15.2, R16.1, U1.15 (GND), U1.45 (GND), U2.10 (GND), U3.10 (GND), U4.10 (GND), U5.10 (GND)
GPIO_TX: J5.5, U5.9 (A8)
GPIO_TX_L: J1.21, U5.11 (B8)
HALT: D1.1 (K), J2.9, R6.2, SW2.2, U1.9 (HALT)
HALT_DBG: D1.2 (A), U5.3 (A2)
HALT_DBG_L: J1.16, U5.17 (B2)
INIT_SW: J1.3, SW1.2
INIT_n: J3.28, R13.2, U1.33 (~INIT), U4.4 (A3)
INIT_n_L: J1.11, U4.16 (B3)
IRQ0: J2.10, U1.10 (IRQ0), U3.2 (A1)
IRQ0_L: J1.6, U3.18 (B1)
IRQ1: J2.11, U1.11 (IRQ1), U3.4 (A3)
IRQ1_L: J1.7, U3.16 (B3)
IRQ2: J2.12, R7.2, U1.12 (IRQ2)
IRQ3: J2.13, R8.2, U1.13 (IRQ3)
LED_RGB: J1.27, J6.3
MAP_n: J2.19, U1.19 (~MAP)
MISS_n: J2.28, R11.2, U1.28 (~MISS)
unnamed: LED1.1 (K), R16.2
OE_n: J4.2, R15.1, U2.19 (*OE), U3.19 (*OE), U4.19 (*OE), U5.19 (*OE)
PARITY_n: J2.14, R9.2, U1.14 (~PARITY)
PRDC_n: J2.29, U1.29 (~PRDC)
PWRF_n: J2.6, R4.2, U1.6 (~PWRF)
SCTL_n: J3.23, U1.38 (~SCTL), U5.6 (A5)
SCTL_n_L: J1.23, U5.14 (B5)
STRB_n: J3.22, U1.39 (~STRB)
TEST1_n: J2.1, R3.2, U1.1 (~TEST1)
TEST2_n: J3.30, R14.2, U1.31 (~TEST2)
XTALI: C2.2, J3.25, R1.2, U1.36 (XTALI), Y1.1
XTALO: C1.2, J3.24, R1.1, U1.37 (XTALO), Y1.2

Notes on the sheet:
isolate FPGA and CPU
72 71 53(high IIL) 52(high IIL)
73 74 (maybe slow)75 85 (GCLKT_1)77 (LED0)15 (LED1)16 27 28 25 (high IIH)26 29 30 31 (LED2)17 (LED5)20 (LED4)19 (LED3)18
76(GCLKC_1) 80(GCLKT_0) 42 41 56 54 51 48 55 49 86 79(RGB onboard)
Some pins are pulled up/down on the board. pin75: 10K (and 100nF early version) to GND and BL616_BOOT pin26: 5.1K to GND (IIH=0.6mA) pin15 to 20: 510R and LED to 5V (IIL=3.0mA) pin52, 53: 2.2K to 3.3V, FET and 2.2K to 5V (IIL=4.4mA)
The value of R1 depends on the LED
TX->RX
pin75 is 10K pulled down to GND on the tang nano board.

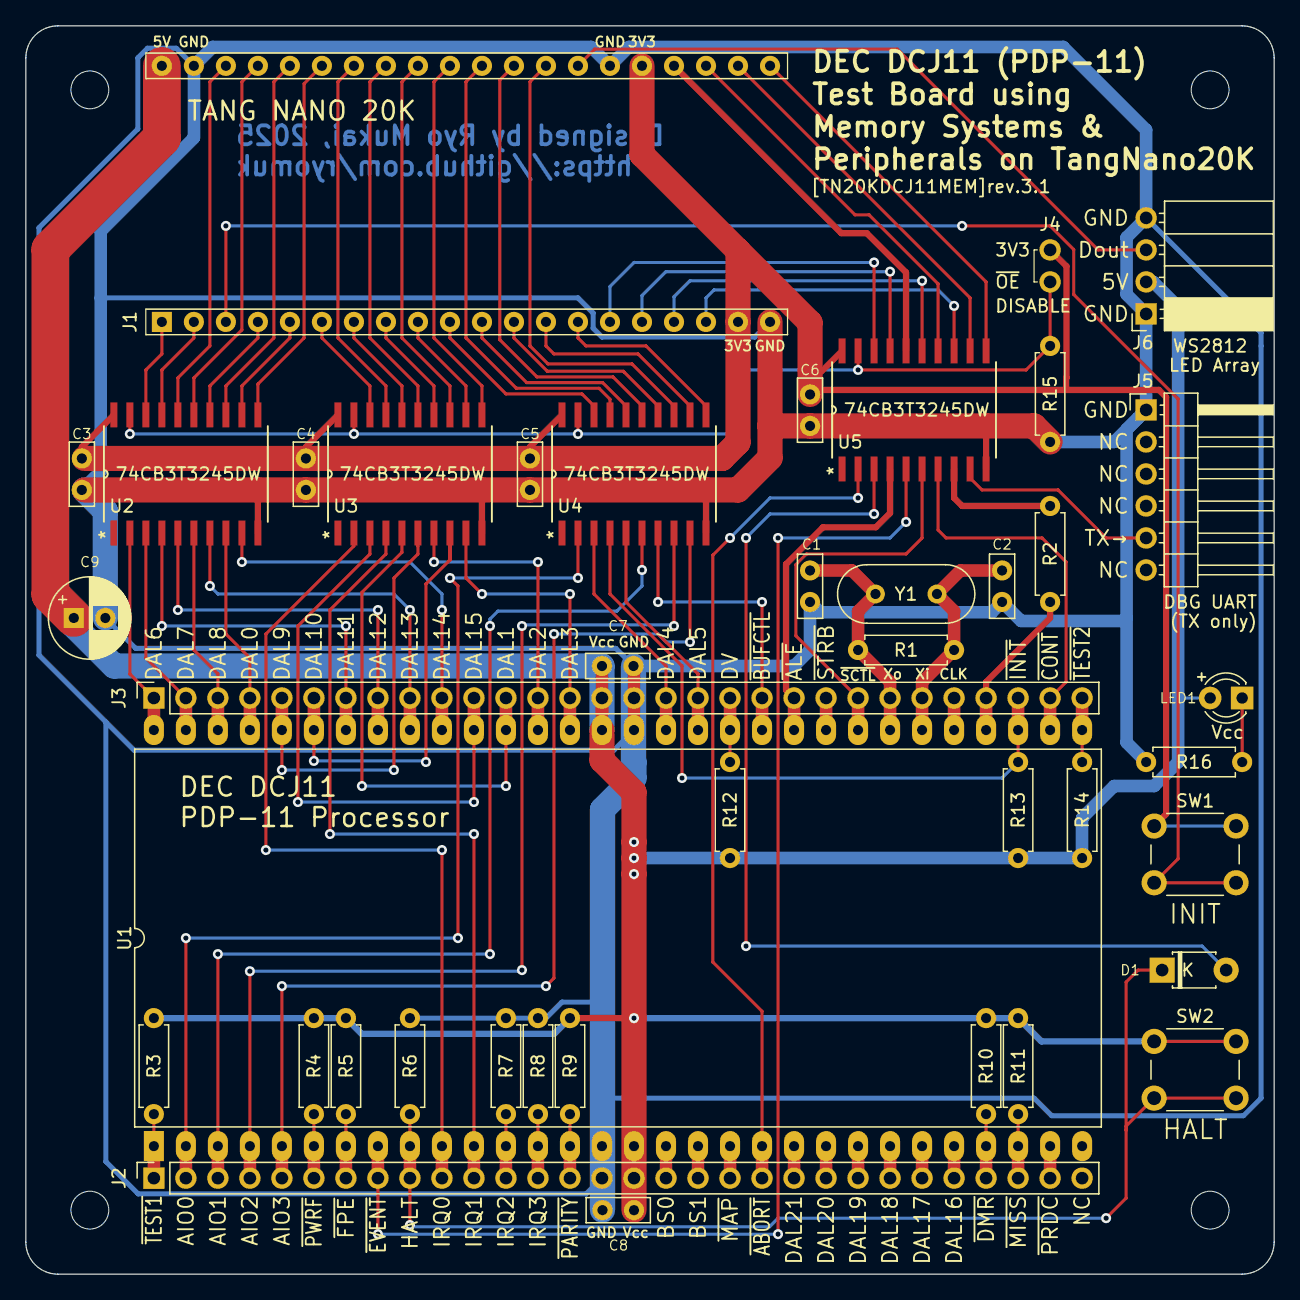
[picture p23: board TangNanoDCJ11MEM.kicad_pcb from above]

Board: 2 copper layers, 99.1 x 99.1 mm, 41 parts (0 on the bottom side), 97 nets.

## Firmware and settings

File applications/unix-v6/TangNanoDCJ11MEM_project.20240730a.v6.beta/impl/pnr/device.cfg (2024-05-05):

set JTAG regular_io = false
set SSPI regular_io = true
set MSPI regular_io = false
set READY regular_io = false
set DONE regular_io = false
set I2C regular_io = false
set RECONFIG_N regular_io = false
set CRC_check = true
set compress = false
set encryption = false
set security_bit_enable = true
set bsram_init_fuse_print = true
set background_programming = off
set secure_mode = false
set program_done_bypass = false
set wake_up = 0
set format = binary
set power_on_reset_monitor = true
set multiboot_spi_flash_address = 0x00000000
set vccx = 3.3
set unused_pin = default

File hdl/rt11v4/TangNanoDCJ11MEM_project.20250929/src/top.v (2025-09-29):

//---------------------------------------------------------------------------
// TangNanoDCJ11MEM
// Memory system and peripherals on TangNano20K for DEC DCJ11 (PDP11)
// for PCB rev.2.x and rev.3.x(and patched rev.1.1)
//
// version 20250929
//
// by Ryo Mukai (https://github.com/ryomuk)
//
// The emulatior of the following peripherals are implemented
// for running the UNIX first edition (UNIX V1).
// - KL11   TTY
// - RF11   drum
// - RK11   disk
// - KW11-L line time clock
// - KE11-A extended arithmetic unit
//
// 2024/06/09: - Hard disk (RF11 and RK11) emulator (sdhd.v) implemented
// 2024/06/10: - KW11-L emulator implemented
// 2024/06/11: - KE11-A emulator implemented
// 2024/06/24: - initial version (very unstable)
// 2024/07/10: - separate command reception for RF11 and RK11
// 2024/07/13: - IRQ bug fixed
// 2024/07/14: - debug register address changed
// 2024/07/15: - Stretched cycle installed for RF, RK, RE11
//               - CONT_n is assigned to LED3.
//             - IRQ2 and IRQ3 are removed. LED2_n is free.
//             - Memory sytem modified to single port RAM
// 2024/07/19: - Relatively stable compared to previous versions.
// 2024/07/27: - Stabilized disk ready logic for IRQ_RFRK (dirty workaround)
//             - Bufferd TX (uart.v) implemented
//             - Some features for UNIX V6 Experiments
//               - ABORT_n installed (pin is LED[2]_n)
//                 write to 160000-167777 or read 177700 causes bus error
//               - Make RAM 28KW (160000-177777 is a ROM area)
//               - boot from RK0 disk (174000g)
// 2024/07/28: - read 160000-160077 causes bus error
// 2024/07/29: - ABORT_n changed to tri-state
//             - bus error condition changed
//                 read 170000-170077 or 177700 causes bus error
// 2024/07/30: - multiple RK disks supported
//
// ****Major update***
// 2025/08/26: - modified to use CLK2 (GPIO_RX is removed)
//
// 2025/09/15: - ws2812 module updated for LED array
// 2025/09/17: - bugfix for using without SD memory
// 2025/09/21: - sw2_toggle and sw2_count installed for debug
// 2025/09/29: - invoke IRQ_ttyo at 60Hz (dirty workaround to boot RT-11)
//---------------------------------------------------------------------------

// Commenting out the following `define makes the GPIO mirror the console,
// but the timing constraints may need to be modified.
`define USE_GPIOUART_DEBUG

module top(
    input	 sw1,
    input	 sw2,
    input	 sys_clk27, // 27MHz system clock
    input	 usb_rx,
    output	 usb_tx,

    input	 CLK2,
    output	 GPIO_TX,

    output	 sd_clk,
    output	 sd_mosi, 
    input	 sd_miso,
    output	 sd_cs_n,
	   
    inout [15:0] DAL,
    input [3:0]	 AIO,
    output	 IRQ0,
    output	 IRQ1,
    inout	 ABORT_n,
    output	 EVENT_n,
    input	 INIT_SW,
    output	 INIT_n, // CPU reset signal
    input	 BUFCTL_n,
    input	 ALE_n,
    input	 SCTL_n,
    output	 CONT_n,
    output	 HALT,

    output	 LED_RGB
    );

//---------------------------------------------------------------------------
// Clock signals
//---------------------------------------------------------------------------
  // system clock
  parameter	 SYS_CLK_FRQ  = 18_000_000; //Hz
  wire		 sys_clk      = CLK2;

  // CPU clock stops while INIT, 
  // so another clock is required for the initialization
  parameter	 INIT_CLK_FRQ = 27_000_000; // Hz
  wire		 init_clk     = sys_clk27;
  
  // clock for sdhd module
  parameter	 SDHD_CLK_FRQ = SYS_CLK_FRQ;
  wire		 sdhd_clk     = sys_clk;

  // clock for RGB LED (must be 27MHz for current implementation)
  parameter	 LED_CLK_FRQ  = 27_000_000;
  wire		 led_clk      = sys_clk27;

//---------------------------------------------------------------------------
// UART BPS
//---------------------------------------------------------------------------
//  parameter	 UART_BPS    =        110; //Hz (needs appropriate serial IF)
//  parameter	 UART_BPS    =        300; //Hz (minimum speed of FT232)
//  parameter	 UART_BPS    =       1200; //Hz (minimum speed of TangNano USB)
//  parameter	 UART_BPS    =       9600; //Hz
//  parameter	 UART_BPS    =      38400; //Hz
  parameter	 UART_BPS    =     115200; //Hz

//---------------------------------------------------------------------------
// RF11 drum
//---------------------------------------------------------------------------
  parameter ADRS_RF_DCS  = 16'o177460; // Disk Control Status Register
    parameter RF_DCS_GO    = 1'b1;  // [0]
    parameter RF_DCS_WRITE = 2'b01; // [2:1]
    parameter RF_DCS_READ  = 2'b10; // [2:1]
  parameter ADRS_RF_WC   = 16'o177462; // Word Count Register
  parameter ADRS_RF_CMA  = 16'o177464; // Current Memory Address Register
  parameter ADRS_RF_DAR  = 16'o177466; // Disk Address Register
  parameter ADRS_RF_DAE  = 16'o177470; // Disk Address Ext & Error Register
  parameter ADRS_RF_DBR  = 16'o177472; // Disk Buffer Register
  parameter ADRS_RF_MAR  = 16'o177474; // Maintenance Register
  parameter ADRS_RF_ADS  = 16'o177476; // Address of Disk Segment Register

  reg [15:0] REG_RF_DCS;
  reg [15:0] REG_RF_WC;
  reg [15:0] REG_RF_CMA;
  reg [15:0] REG_RF_DAR;
  reg [15:0] REG_RF_DAE;
  reg [15:0] REG_RF_ADS;

  reg [15:0] REG_RF_WC_BAK;
  reg [15:0] REG_RF_CMA_BAK;
  reg [15:0] REG_RF_DAR_BAK;
  reg [15:0] REG_RF_DAE_BAK;
  
//---------------------------------------------------------------------------
// RK11 disk
//---------------------------------------------------------------------------
  parameter ADRS_RKDS = 16'o177400; // Disk Control Status Register
  parameter ADRS_RKER = 16'o177402; // Error Register
  parameter ADRS_RKCS = 16'o177404; // Control Status Register
    parameter RKCS_GO  = 1'b1;      // [0]
    parameter RKCS_CRESET = 3'b000;  // [3:1] 'b0001 = 'o001
    parameter RKCS_WRITE  = 3'b001;  // [3:1] 'b0011 = 'o003
    parameter RKCS_READ   = 3'b010;  // [3:1] 'b0101 = 'o005
    parameter RKCS_SEEK   = 3'b100;  // [3:1] 'b1001 = 'o011
    parameter RKCS_DRESET = 3'b110;  // [3:1] 'b1101 = 'o015
  parameter ADRS_RKWC = 16'o177406; // Word Count Register
  parameter ADRS_RKBA = 16'o177410; // Current Bus Address Register
  parameter ADRS_RKDA = 16'o177412; // Disk Address Register
  parameter ADRS_RKMR = 16'o177414; // Maintenance Register
  parameter ADRS_RKDB = 16'o177416; // Disk Buffer Register

  reg [15:0] REG_RKCS;
  reg [15:0] REG_RKWC;
  reg [15:0] REG_RKBA;
  reg [15:0] REG_RKDA;
  
  reg [15:0] REG_RKWC_BAK;
  reg [15:0] REG_RKBA_BAK;
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

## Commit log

2024-05-05 update for rev1.1
    [device.cfg]
2024-06-24 unixv1 initial commit
    [device.cfg]
2024-06-28 0628.alpha updated
    [device.cfg]
2024-07-02 0702.alpha updated
    [device.cfg, diff.txt]
2024-07-03 0703.alpha uploaded
    [device.cfg, diff.txt]
2024-07-04 0704.alpha uploaded
    [device.cfg, diff.txt]
2024-07-07 baremetal updated
    [device.cfg]
2024-07-07 20240707.alpha uploaded
    [device.cfg]
2024-07-09 20240709.alpha uploaded
    [device.cfg]
2024-07-10 20240710.alpha uploaded
    [device.cfg]
2024-07-12 20240712.alpha uploaded
    [device.cfg]
2024-07-13 20240713.alpha uploaded
    [device.cfg]
2024-07-14 20240714.alpha uploaded
    [device.cfg]
2024-07-15 R2-6 changed
    [TangNanoDCJ11MEM.kicad_sch]
2024-07-16 20240716.beta uploaded
    [device.cfg]
2024-07-19 20240719.beta uploaded
    [device.cfg]
2024-07-26 20240726.beta uploaded
    [device.cfg]
2024-07-26 20240726.beta cancelled
    [device.cfg]
2024-07-27 20240727.beta updated
    [device.cfg]
2024-07-28 20240728.beta uploaded
    [device.cfg]
2024-07-29 20240729.beta uploaded
    [device.cfg]
2024-07-29 20240730.v6.beta uploaded
    [device.cfg]
2024-07-30 20240730a.v6.beta uploaded
    [device.cfg]
2025-09-04 update for PCB rev2
    [TangNanoDCJ11MEM-B_Cu.gbr, TangNanoDCJ11MEM-B_Mask.gbr, TangNanoDCJ11MEM-B_Paste.gbr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]
2025-09-05 PCB rev2.1 released
    [TangNanoDCJ11MEM-B_Cu.gbr, TangNanoDCJ11MEM-B_Mask.gbr, TangNanoDCJ11MEM-B_Paste.gbr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]
2025-09-05 PCB rev2.2 released
    [TangNanoDCJ11MEM-B_Cu.gbr, TangNanoDCJ11MEM-B_Mask.gbr, TangNanoDCJ11MEM-B_Paste.gbr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]
2025-09-15 code for rev2 updated
    [device.cfg]
2025-09-17 20250917.pcbrev2 released
    [device.cfg]
2025-09-22 major update
    [TangNanoDCJ11MEM-B_Cu.gbr, TangNanoDCJ11MEM-B_Mask.gbr, TangNanoDCJ11MEM-B_Paste.gbr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]
2025-09-22 pcb rev3.1 released
    [TangNanoDCJ11MEM-B_Cu.gbr, TangNanoDCJ11MEM-B_Mask.gbr, TangNanoDCJ11MEM-B_Paste.gbr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]
2025-09-26 impl folders removed
    [device.cfg]
